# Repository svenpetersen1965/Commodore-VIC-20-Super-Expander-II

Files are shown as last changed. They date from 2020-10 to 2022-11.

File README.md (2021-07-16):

# Commodore-VIC-20-Super-Expander-II
This is a reverse engineered  Commodore Super Expander cartridge which does not have the original ROM pinouts, but fits 27C512 EPROMs. The 8k memory bank and the other configuration can be  selected with jumpers or solder bridges.

This cartridge provides a 3k RAM expansion (required for Super Expander) and up to two EPROMs and is of general use for games and especially the VIC-20 diagnostic software.

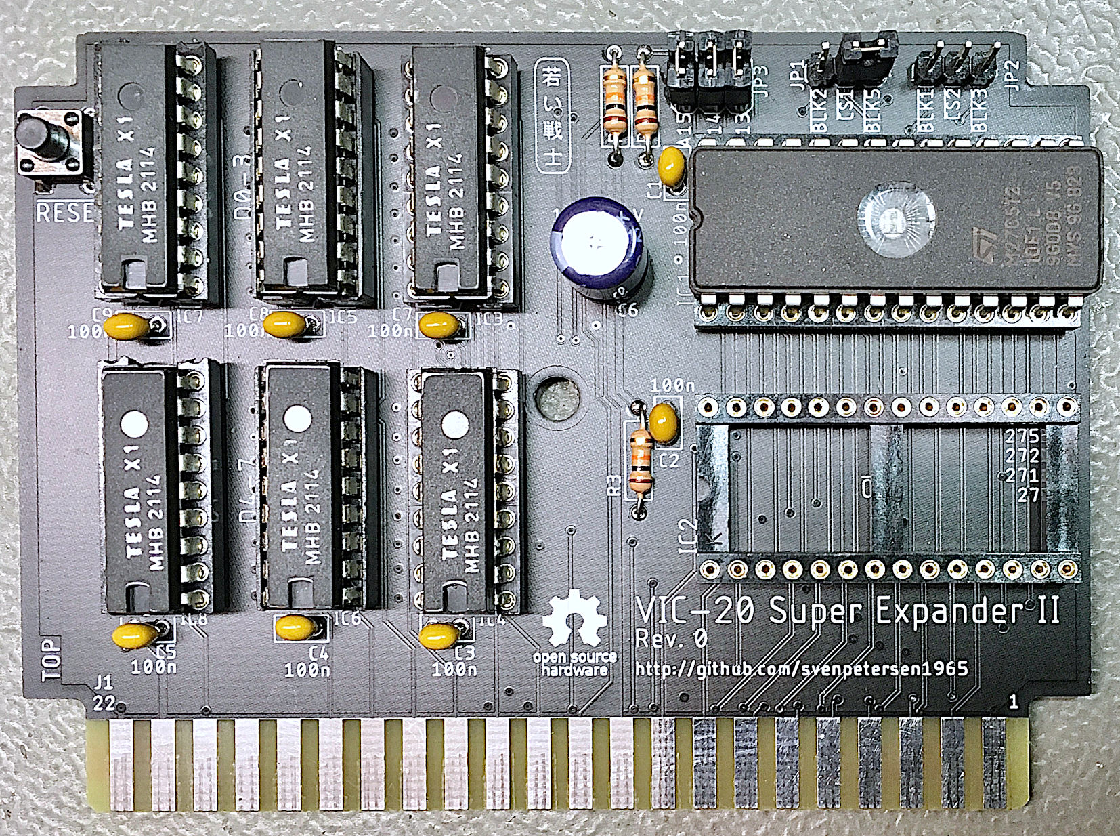
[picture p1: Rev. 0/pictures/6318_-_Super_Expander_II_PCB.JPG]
Super Expander II


Please also check my <a href="http://tech.guitarsite.de/vic-20_super_expanderii.html">website</a>.

BOM value (full): 21.39€ (12.12.2020)

# Rev. 1

Rev. 1 allows to select a software size of 4k and 8k. This allows to combine the super expander software with a cartridge that resides at $B000. This requires a multi cartridge box (like the VC-1020). It is for 100% compatibility to teh original. Also a new logo was introduced.

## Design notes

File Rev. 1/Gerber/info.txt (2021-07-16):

      
       Board: VIC20_SExpII
       Rev.:  1
  
       Files:
       ======
  
       All Gerber files are generated in extended gerber format (RS274X)
       *.TOP        : Film top copper
       *.BOT        :  -"- bottom copper
       *.STC        :  -"- top soldermask 
       *.STS        :  -"- bottom soldermask
       *.PLC        :  -"- silk screen top
       *.DK         : Drills plated Through (Excellon)
       *.NDK        : Drills not plated Through (Excellon)
       *.OUT        : Board outline

       Board Size:
       ===========
       Length     :   102.0 mm
       Width      :   75.0 mm
       Thickness  :   1.6 mm
       Material   :   FR 4
       Copper     :   35 um
       Surface    :   HASL
       
       Remarks:
       ========
       Width >= 8mil
       Distance >= 6mil
       Drill >= 0.35mm

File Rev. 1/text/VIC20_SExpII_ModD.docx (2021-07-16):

Commodore VIC-20: Super Expander II Rev. 1

Module Description

# General Description

The original Commodore VIC-1211A Super Expander is a Basic Extension, which contains high resolution graphics and sound commands and additional 3kB of RAM. It is a pretty versatile cartridge, which allows up to two 2364 ROMs, that can be configured to use either the 8k chip-selects /BLK2, /BLK5, /BLK1or /BLK3. The configuration is done with solder bridges.

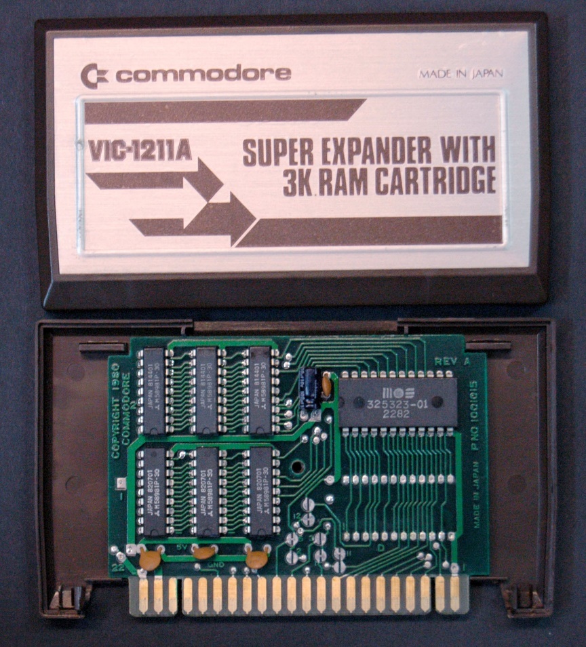
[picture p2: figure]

Figure 1: The Commodore VIC-1211A Super Expander Cartridge

With less RAM (1k) and another software, the same PCB is used as a (Commodore) diagnostic cartridge for the VIC-20.

The disadvantage for own projects is the usage of 2364/2332 ROMs. Thus, the Super Expander II is a version of the original Super Expander cartridge that can fit up to two 27C512 EPROMs. The configuration is done with jumpers, which also work as solder bridges (no pin header required), in case the configuration is not desired to be changed.

Two of the chip-select signals apply to each EPROM. The 8k memory bank can be selected with three jumpers. The selection applies to both EPROMs.

The 2114 4x1k (static) RAMs are the same, like in the original Super Expander. They are still available from some retro computer stores for a comparatively good price and also from AliExpress (search term “upd2114”).

# Configuration

## Chip selects

EPROM | Jumper | Chip Select | VIC-20 Address
IC1 | JP1 | | $4000 - $5FFF
| | | $A000 - $BFFF
IC2 | JP2 | | $2000 - $3FFF
| | | $6000 - $7FFF

Table 1: Configurable Chip Selects

## RAM Address

RAM | Chip Select | VIC-20 Address
IC3 (bit 0-3) IC4 (bit 4-7) | | $0400 - $07FF
IC5 (bit 0-3) IC6 (bit 4-7) | | $0800 - $0BFF
IC7 (bit 0-3) IC8 (bit 4-7) | | $0C00 - $0FFF

Table 2: Mapping of the RAM ICs

## Software Size

The original Super Expander used a 2332 ROM, which had a 2nd, low active chip select input, which disabled the ROM while A12 (connected to this 2nd input) was HIGH. This way, the Super Expander can be combined with cartridges, that use the $B000 - $BFFF address space, like the machine language monitor cartridge. The Super Expander II resembles this behavior by optionally setting the chip enable input of the EPROMs HIGH (with A12). This can be selected with JP4 (for IC1) or JP5 (for IC2) being set to “4k”. Default setting is “8k” (chip enable = LOW).

The address range of the EPROMs (as seen by the CPU) with JP4 ond/or JP5 set to “4k”

EPROM | Jumper | Chip Select | VIC-20 Address
IC1 | JP1 | | $4000 - $4FFF
| | | $A000 - $AFFF
IC2 | JP2 | | $2000 - $2FFF
| | | $6000 - $6FFF

## Memory Bank Select

There are two different types of addresses mentioned in this document:

- VIC-20 Address
- EPROM Offset Address

Both types must not be confused! The EPROM Offset Address is the address of the selected memory bank within (the program buffer of the EPROM). This is, where you load the different binary files to the EPROM buffer. One of those memory banks is selected with the Jumper JP3. This appears in/is mapped to the VIC-20 memory at the address determined by the chip select (see Table 1).

JP3 | | | Address Bits | | | EPROM Address (Offset)
A15 | A14 | A35 | A15 | A14 | A13
SET | SET | SET | L | L | L | 0x0000 – 0x1FFF
SET | SET | OPEN | L | L | H | 0x2000 – 0x3FFF
SET | OPEN | SET | L | H | L | 0x4000 – 0x5FFF
SET | OPEN | OPEN | L | H | H | 0x6000 – 0x7FFF
OPEN | SET | SET | H | L | L | 0x8000 – 0x9FFF
OPEN | SET | OPEN | H | L | H | 0xA000 – 0xBFFF
OPEN | OPEN | SET | H | H | L | 0xC000 – 0xDFFF
OPEN | OPEN | OPEN | H | H | H | 0xE000 – 0xFFFF

Table 3: 8k cartridges memory banks

# EPROMs

Four different types/sizes of EPROMs can be used with the Super Expander II, not all settings make sense with them. Their pin out is shown in Table 4.

The effect of the settings and the recommended configurations are shown in Table 5.

27C64
| 27C128
| | 27C256
| | | 27C512
| | | | SOCKET
Vpp | Vpp | Vpp | A15 | 1 | A15 | VCC | 28 | VCC | VCC | VCC | VCC
A12 | A12 | A12 | A12 | 2 | A12 | A14 | 27 | A14 | A14 | /PGM | /PGM
A7 | A7 | A7 | A7 | 3 | A7 | A13 | 26 | A13 | A13 | A13 | n.c.
A6 | A6 | A6 | A6 | 4 | A6 | A8 | 25 | A8 | A8 | A8 | A8
A5 | A5 | A5 | A5 | 5 | A5 | A9 | 24 | A9 | A9 | A9 | A9
A4 | A4 | A4 | A4 | 6 | A4 | A11 | 23 | A11 | A11 | A11 | A11
A3 | A3 | A3 | A3 | 7 | A3 | /OE | 22 | /G/Vpp | /G | /G | /G
A2 | A2 | A2 | A2 | 8 | A2 | A10 | 21 | A10 | A10 | A10 | A10
A1 | A1 | A1 | A1 | 9 | A1 | GND | 20 | /E | /E | /E | /E
A0 | A0 | A0 | A0 | 10 | A0 | D7 | 19 | D7 | D7 | D7 | D7
D0 | D0 | D0 | D0 | 11 | D0 | D6 | 18 | D6 | D6 | D6 | D6
D1 | D1 | D1 | D1 | 12 | D1 | D5 | 17 | D5 | D5 | D5 | D5
D2 | D2 | D2 | D2 | 13 | D2 | D4 | 16 | D4 | D4 | D4 | D4
GND | GND | GND | GND | 14 | GND | D3 | 15 | D3 | D3 | D3 | D3

Table 4: EPROM pin compatibility

EPROM | Size | A15 | A14 | A13
27C512 | 64kx8 | yes | yes | yes
27C256 | 32kx8 | HIGH | yes | yes
27C128 | 16kx8 | HIGH | HIGH | yes
27C64 | 8kx8 | HIGH | HIGH | HIGH

Table 5: Settings per EPROM type

In case Vpp is located at a dedicated pin (pin 1), A15 has no effect anymore. A HIGH level is recommended (switch is off). The /PGM Pin should be set HIGH. The n.c. (not connected) pin should be HIGH (with pull-up resistor) or open.

# Using parallel EEPROMs

There are parallel EPROMs, which fit into the EPROM sockets. They do not require erasing with a UV eraser, like EPROMs, but the price is higher.

Since they can be written, which is controlled by the signal, but the Super Expander II cartridge is lacking of this functionality, this signal has to be HIGH (inactive). The 28C256 has the A14 signal connected to Pin 1, which is A15 of the EEPROM socket. This is no problem, but it has to be kept in mind, that the jumper for A15 has effect on the bank select A14 of the EPROM.

28C64
| 28C256
| | SOCKET
n.c. | A14 | 1 | A15 | VCC | 28 | VCC | VCC
A12 | A12 | 2 | A12 | A14 | 27 | /WE | /WE
A7 | A7 | 3 | A7 | A13 | 26 | A13 | n.c
A6 | A6 | 4 | A6 | A8 | 25 | A8 | A8
A5 | A5 | 5 | A5 | A9 | 24 | A9 | A9
A4 | A4 | 6 | A4 | A11 | 23 | A11 | A11
A3 | A3 | 7 | A3 | /OE | 22 | /G/Vpp | /OE
A2 | A2 | 8 | A2 | A10 | 21 | A10 | A10
A1 | A1 | 9 | A1 | GND | 20 | /E | /CE
A0 | A0 | 10 | A0 | D7 | 19 | D7 | D7
D0 | D0 | 11 | D0 | D6 | 18 | D6 | D6
D1 | D1 | 12 | D1 | D5 | 17 | D5 | D5
D2 | D2 | 13 | D2 | D4 | 16 | D4 | D4
GND | GND | 14 | GND | D3 | 15 | D3 | D3

Table 6: EEPROM pin compatibility

EEPROM | Size | A15 | A14 | A13
28C256 | 32kx8 | =A14 | OPEN | yes
28C64 | 8kx8 | OPEN | OPEN | OPEN

Table 7: Settings per EEPROM type

# Dimensions

The dimensions of the Super Expander II are identical to those of the original super Expander PCB.

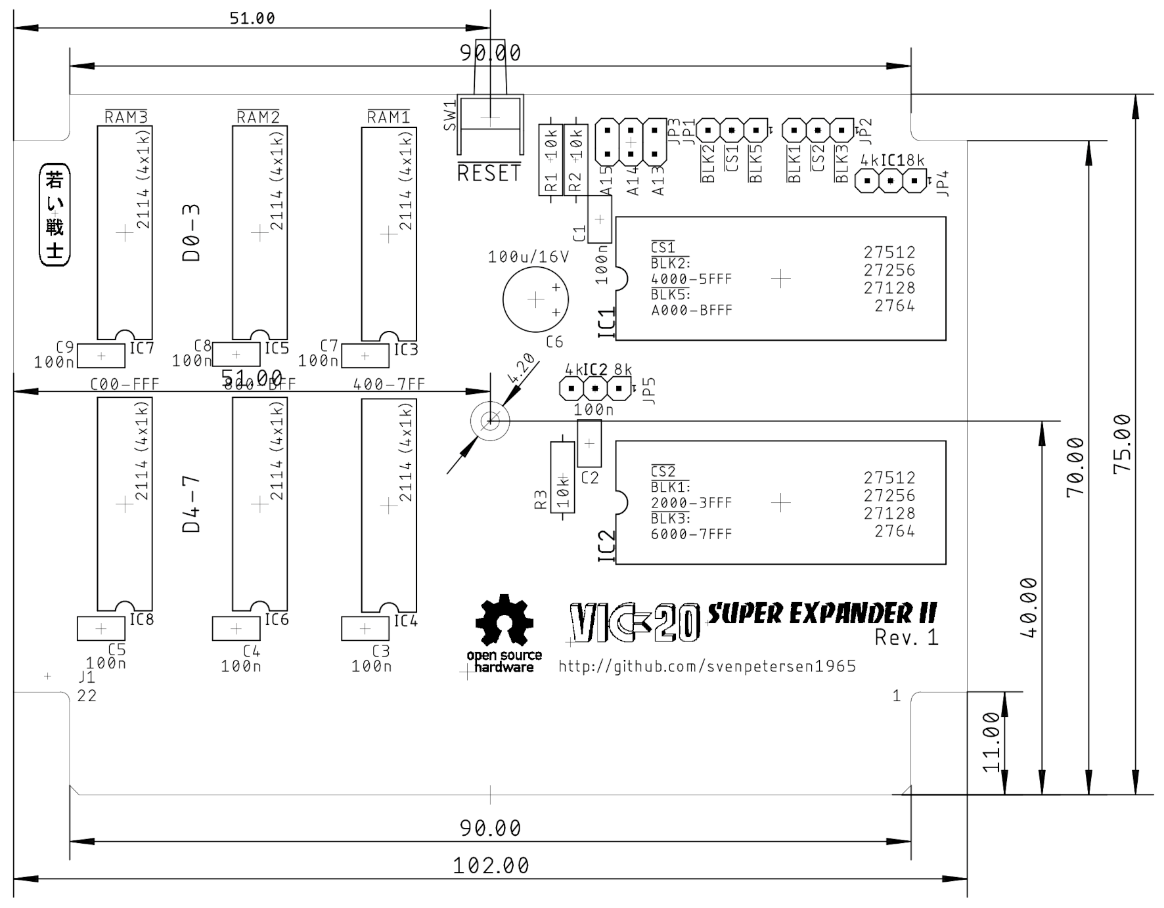
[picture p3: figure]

Figure 2: Dimensions of the Super Expander II

The PCB fits the original super Expander cartridge case, another VIC-20 cartridge case from Commodore or the tfw8bit.com cartridge case.

The VIC-20 cartridge cases are high enough to fits the Super Expander II PCB even with the ICs on sockets and vertical jumpers. This has been verified for the Super Expander case and the tfw8bit case. The tfw8bit case and the “other Commodore VIC-20” cases require two T-shaped board supports in the middle of the lower shell to be removed.

# Revision History

## Rev. 0

- Prototype: Fully functional.

## Rev. 1

- 4k address decoding (lower 4k) enabled
- Type and location of reset switch changed
- Cool new logo

VIC20_SExpII_ModD.docx 16.07.2021 15:38 Drafted by Sven Petersen Page 2 of 2 Doc.-No.: 157-6-01-01

VIC20_SExpII_ModD.docx 16.07.2021 15:38 Drafted by Sven Petersen Page 1 of 1 Doc.-No.: 1-6-00-00

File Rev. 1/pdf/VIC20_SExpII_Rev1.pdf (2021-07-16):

# Project Documentation

## Commodore VIC-20: Super Expander II

## Project number: 157

## Revision: 1

## Date: 16.07.2021

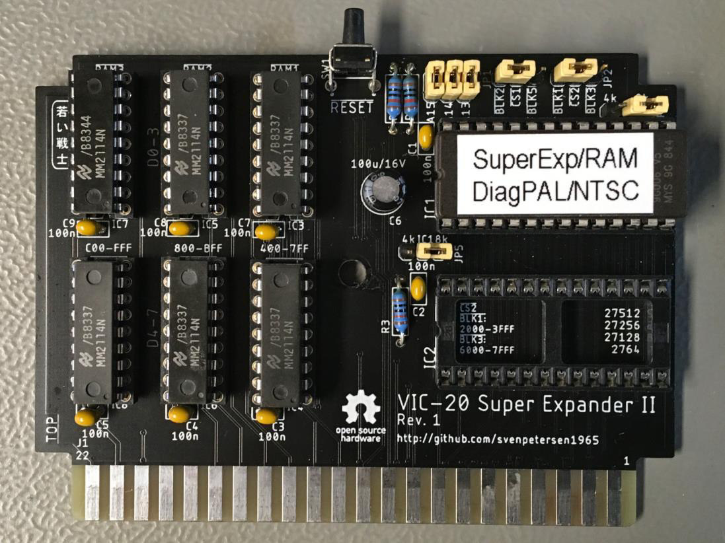
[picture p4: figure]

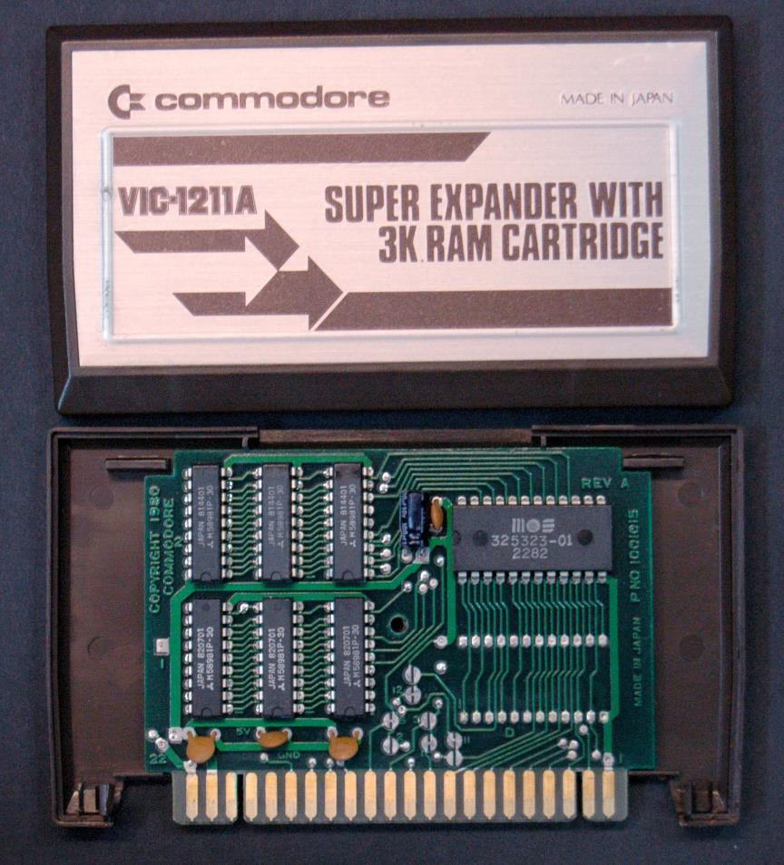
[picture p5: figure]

VIC20_SExpII_ModD.docx | | 16.07.2021 15:38
Drafted by Sven Petersen | Page 1 of 6 | Doc.-No.: 157-6-01-01

### Commodore VIC-20: Super Expander II Rev. 1

### Module Description

## General Description

The original Commodore VIC-1211A Super Expander is a Basic Extension, which contains high resolution graphics and sound commands and additional 3kB of RAM. It is a pretty versatile cartridge, which allows up to two 2364 ROMs, that can be configured to use either the 8k chip-selects /BLK2, /BLK5, /BLK1or /BLK3. The configuration is done with solder bridges.

Figure 1: The Commodore VIC-1211A Super Expander Cartridge

With less RAM (1k) and another software, the same PCB is used as a (Commodore) diagnostic cartridge for the VIC-20.

The disadvantage for own projects is the usage of 2364/2332 ROMs. Thus, the Super Expander II is a version of the original Super Expander cartridge that can fit up to two
27C512 EPROMs. The configuration is done with jumpers, which also work as solder bridges (no pin header required), in case the configuration is not desired to be changed.

Two of the chip-select signals apply to each EPROM. The 8k memory bank can be selected with three jumpers. The selection applies to both EPROMs.

The 2114 4x1k (static) RAMs are the same, like in the original Super Expander. They are still available from some retro computer stores for a comparatively good price and also from
AliExpress (search term “upd2114”).

VIC20_SExpII_ModD.docx | | 16.07.2021 15:38
Drafted by Sven Petersen | Page 2 of 6 | Doc.-No.: 157-6-01-01

## Configuration

### Chip selects

EPROM | Jumper | Chip Select | VIC-20 Address
IC1 | JP1 | BLK2 | $4000 - $5FFF
| | BLK5 | $A000 - $BFFF
IC2 | JP2 | BLK1 | $2000 - $3FFF
| | BLK3 | $6000 - $7FFF

Table 1: Configurable Chip Selects

### RAM Address

RAM | Chip Select | VIC-20 Address
IC3 (bit 0-3) IC4 (bit 4-7) | RAM1 | $0400 - $07FF
IC5 (bit 0-3) IC6 (bit 4-7) | RAM2 | $0800 - $0BFF
IC7 (bit 0-3) IC8 (bit 4-7) | RAM3 | $0C00 - $0FFF

Table 2: Mapping of the RAM ICs

### Software Size

The original Super Expander used a 2332 ROM, which had a 2nd, low active chip select input, which disabled the ROM while A12 (connected to this 2nd input) was HIGH. This way, the Super Expander can be combined with cartridges, that use the $B000 - $BFFF address space, like the machine language monitor cartridge. The Super Expander II resembles this behavior by optionally setting the chip enable input of the EPROMs HIGH (with A12). This can be selected with JP4 (for
IC1) or JP5 (for IC2) being set to “4k”. Default setting is “8k” (chip enable = LOW).

### The address range of the EPROMs (as seen by the CPU) with JP4 ond/or JP5 set to “4k”

EPROM | Jumper | Chip Select | VIC-20 Address
IC1 | JP1 | BLK2 | $4000 - $4FFF
| | BLK5 | $A000 - $AFFF
IC2 | JP2 | BLK1 | $2000 - $2FFF
| | BLK3 | $6000 - $6FFF

VIC20_SExpII_ModD.docx | | 16.07.2021 15:38
Drafted by Sven Petersen | Page 3 of 6 | Doc.-No.: 157-6-01-01

### Memory Bank Select

There are two different types of addresses mentioned in this document:

- VIC-20 Address
- EPROM Offset Address

Both types must not be confused! The EPROM Offset Address is the address of the selected memory bank within (the program buffer of the EPROM). This is, where you load the different binary files to the EPROM buffer. One of those memory banks is selected with the Jumper JP3. This appears in/is mapped to the VIC-20 memory at the address determined by the chip select BLK1/2/3/5 (see Table 1).

JP3 | Address Bits | EPROM Address
A15 | A14 | A35 | A15 | A14 | A13 | (Offset)
SET | SET | SET | L | L | L | 0x0000 – 0x1FFF
SET | SET | OPEN | L | L | H | 0x2000 – 0x3FFF
SET | OPEN | SET | L | H | L | 0x4000 – 0x5FFF
SET | OPEN | OPEN | L | H | H | 0x6000 – 0x7FFF
OPEN | SET | SET | H | L | L | 0x8000 – 0x9FFF
OPEN | SET | OPEN | H | L | H | 0xA000 – 0xBFFF
OPEN | OPEN | SET | H | H | L | 0xC000 – 0xDFFF
OPEN | OPEN | OPEN | H | H | H | 0xE000 – 0xFFFF
Table 3: 8k cartridges memory banks

VIC20_SExpII_ModD.docx | | 16.07.2021 15:38
Drafted by Sven Petersen | Page 4 of 6 | Doc.-No.: 157-6-01-01

## EPROMs

Four different types/sizes of EPROMs can be used with the Super Expander II, not all settings make sense with them. Their pin out is shown in Table 4.

The effect of the settings and the recommended configurations are shown in Table 5.

27C64
| 27C128
| 27C256
| 27C512
| SOCKET
Vpp | Vpp | Vpp | A15 | 1 | A15 | VCC | 28 | VCC | VCC | VCC | VCC
A12 | A12 | A12 | A12 | 2 | A12 | A14 | 27 | A14 | A14 | /PGM | /PGM
A7 | A7 | A7 | A7 | 3 | A7 | A13 | 26 | A13 | A13 | A13 | n.c.
A6 | A6 | A6 | A6 | 4 | A6 | A8 | 25 | A8 | A8 | A8 | A8
A5 | A5 | A5 | A5 | 5 | A5 | A9 | 24 | A9 | A9 | A9 | A9
A4 | A4 | A4 | A4 | 6 | A4 | A11 | 23 | A11 | A11 | A11 | A11
A3 | A3 | A3 | A3 | 7 | A3 | /OE | 22 | /G/Vpp | /G | /G | /G
A2 | A2 | A2 | A2 | 8 | A2 | A10 | 21 | A10 | A10 | A10 | A10
A1 | A1 | A1 | A1 | 9 | A1 | GND | 20 | /E | /E | /E | /E
A0 | A0 | A0 | A0 | 10 | A0 | D7 | 19 | D7 | D7 | D7 | D7
D0 | D0 | D0 | D0 | 11 | D0 | D6 | 18 | D6 | D6 | D6 | D6
D1 | D1 | D1 | D1 | 12 | D1 | D5 | 17 | D5 | D5 | D5 | D5
D2 | D2 | D2 | D2 | 13 | D2 | D4 | 16 | D4 | D4 | D4 | D4
GND | GND | GND | GND | 14 | GND | D3 | 15 | D3 | D3 | D3 | D3
Table 4: EPROM pin compatibility
EPROM | Size | A15 | A14 | A13
27C512 | 64kx8 | yes | yes | yes
27C256 | 32kx8 | HIGH | yes | yes
27C128 | 16kx8 | HIGH | HIGH | yes
27C64 | 8kx8 | HIGH | HIGH | HIGH
Table 5: Settings per EPROM type

In case Vpp is located at a dedicated pin (pin 1), A15 has no effect anymore. A HIGH level is recommended (switch is off). The /PGM Pin should be set HIGH. The n.c. (not connected) pin should be HIGH (with pull-up resistor) or open.

VIC20_SExpII_ModD.docx | | 16.07.2021 15:38
Drafted by Sven Petersen | Page 5 of 6 | Doc.-No.: 157-6-01-01

## Using parallel EEPROMs

There are parallel EPROMs, which fit into the EPROM sockets. They do not require erasing with a UV eraser, like EPROMs, but the price is higher.

Since they can be written, which is controlled by the WE signal, but the Super Expander II cartridge is lacking of this functionality, this signal has to be HIGH (inactive). The 28C256 has the A14 signal connected to Pin 1, which is A15 of the EEPROM socket. This is no problem, but it has to be kept in mind, that the jumper for A15 has effect on the bank select A14 of the EPROM.

28C64
| 28C256
| SOCKET
n.c. | A14 | 1 | A15 | VCC | 28 | VCC | VCC
A12 | A12 | 2 | A12 | A14 | 27 | /WE | /WE
A7 | A7 | 3 | A7 | A13 | 26 | A13 | n.c
A6 | A6 | 4 | A6 | A8 | 25 | A8 | A8
A5 | A5 | 5 | A5 | A9 | 24 | A9 | A9
A4 | A4 | 6 | A4 | A11 | 23 | A11 | A11
A3 | A3 | 7 | A3 | /OE | 22 | /G/Vpp | /OE
A2 | A2 | 8 | A2 | A10 | 21 | A10 | A10
A1 | A1 | 9 | A1 | GND | 20 | /E | /CE
A0 | A0 | 10 | A0 | D7 | 19 | D7 | D7
D0 | D0 | 11 | D0 | D6 | 18 | D6 | D6
D1 | D1 | 12 | D1 | D5 | 17 | D5 | D5
D2 | D2 | 13 | D2 | D4 | 16 | D4 | D4
GND | GND | 14 | GND | D3 | 15 | D3 | D3
Table 6: EEPROM pin compatibility
EEPROM | Size | A15 | A14 | A13
28C256 | 32kx8 | =A14 | OPEN | yes
28C64 | 8kx8 | OPEN | OPEN | OPEN
Table 7: Settings per EEPROM type

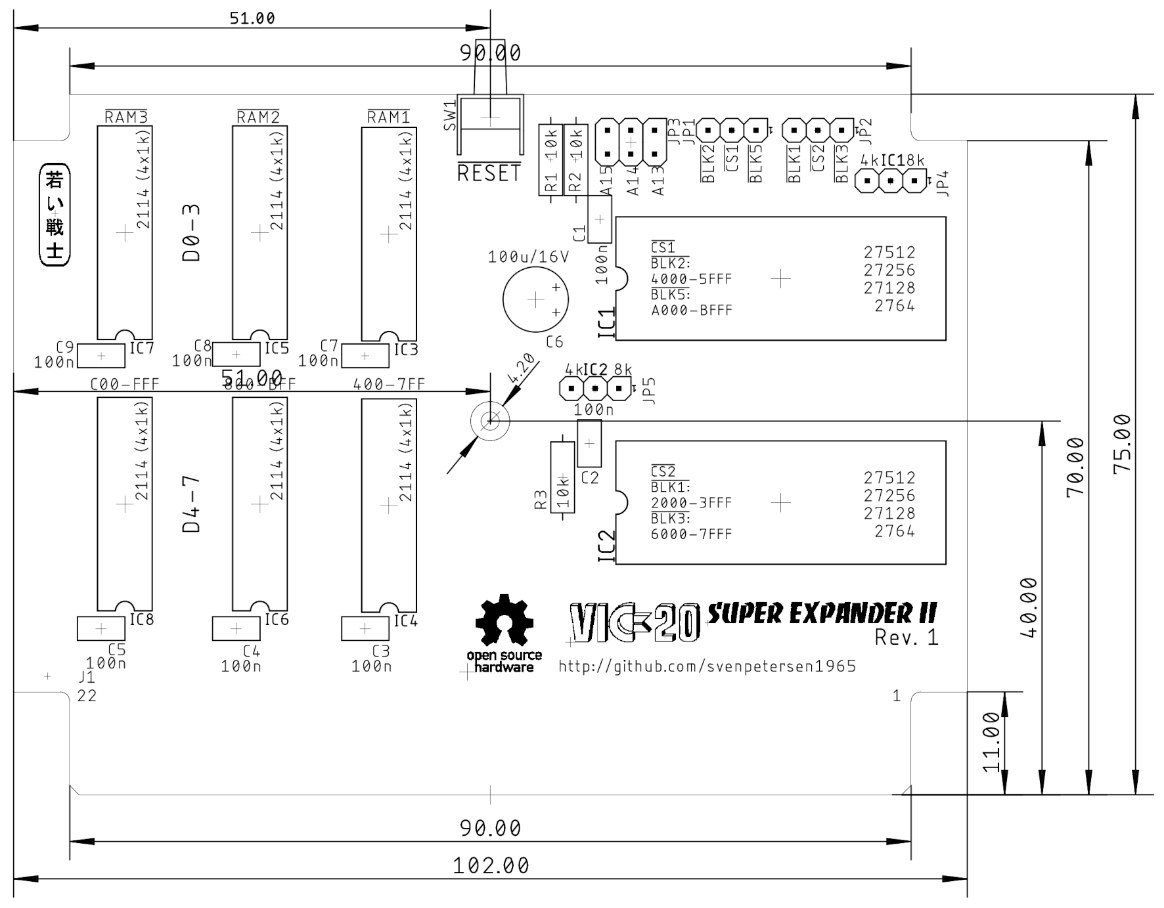
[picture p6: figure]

VIC20_SExpII_ModD.docx | | 16.07.2021 15:38
Drafted by Sven Petersen | Page 6 of 6 | Doc.-No.: 157-6-01-01

## Dimensions

The dimensions of the Super Expander II are identical to those of the original super Expander PCB.

Figure 2: Dimensions of the Super Expander II

The PCB fits the original super Expander cartridge case, another VIC-20 cartridge case from Commodore or the tfw8bit.com cartridge case.

The VIC-20 cartridge cases are high enough to fits the Super Expander II PCB even with the ICs on sockets and vertical jumpers. This has been verified for the Super Expander case and the tfw8bit

### case. The tfw8bit case and the “other Commodore VIC-20” cases require two T-shaped board

supports in the middle of the lower shell to be removed.

## Revision History

### Rev. 0

- Prototype: Fully functional.

### Rev. 1

- 4k address decoding (lower 4k) enabled
- Type and location of reset switch changed
- Cool new logo

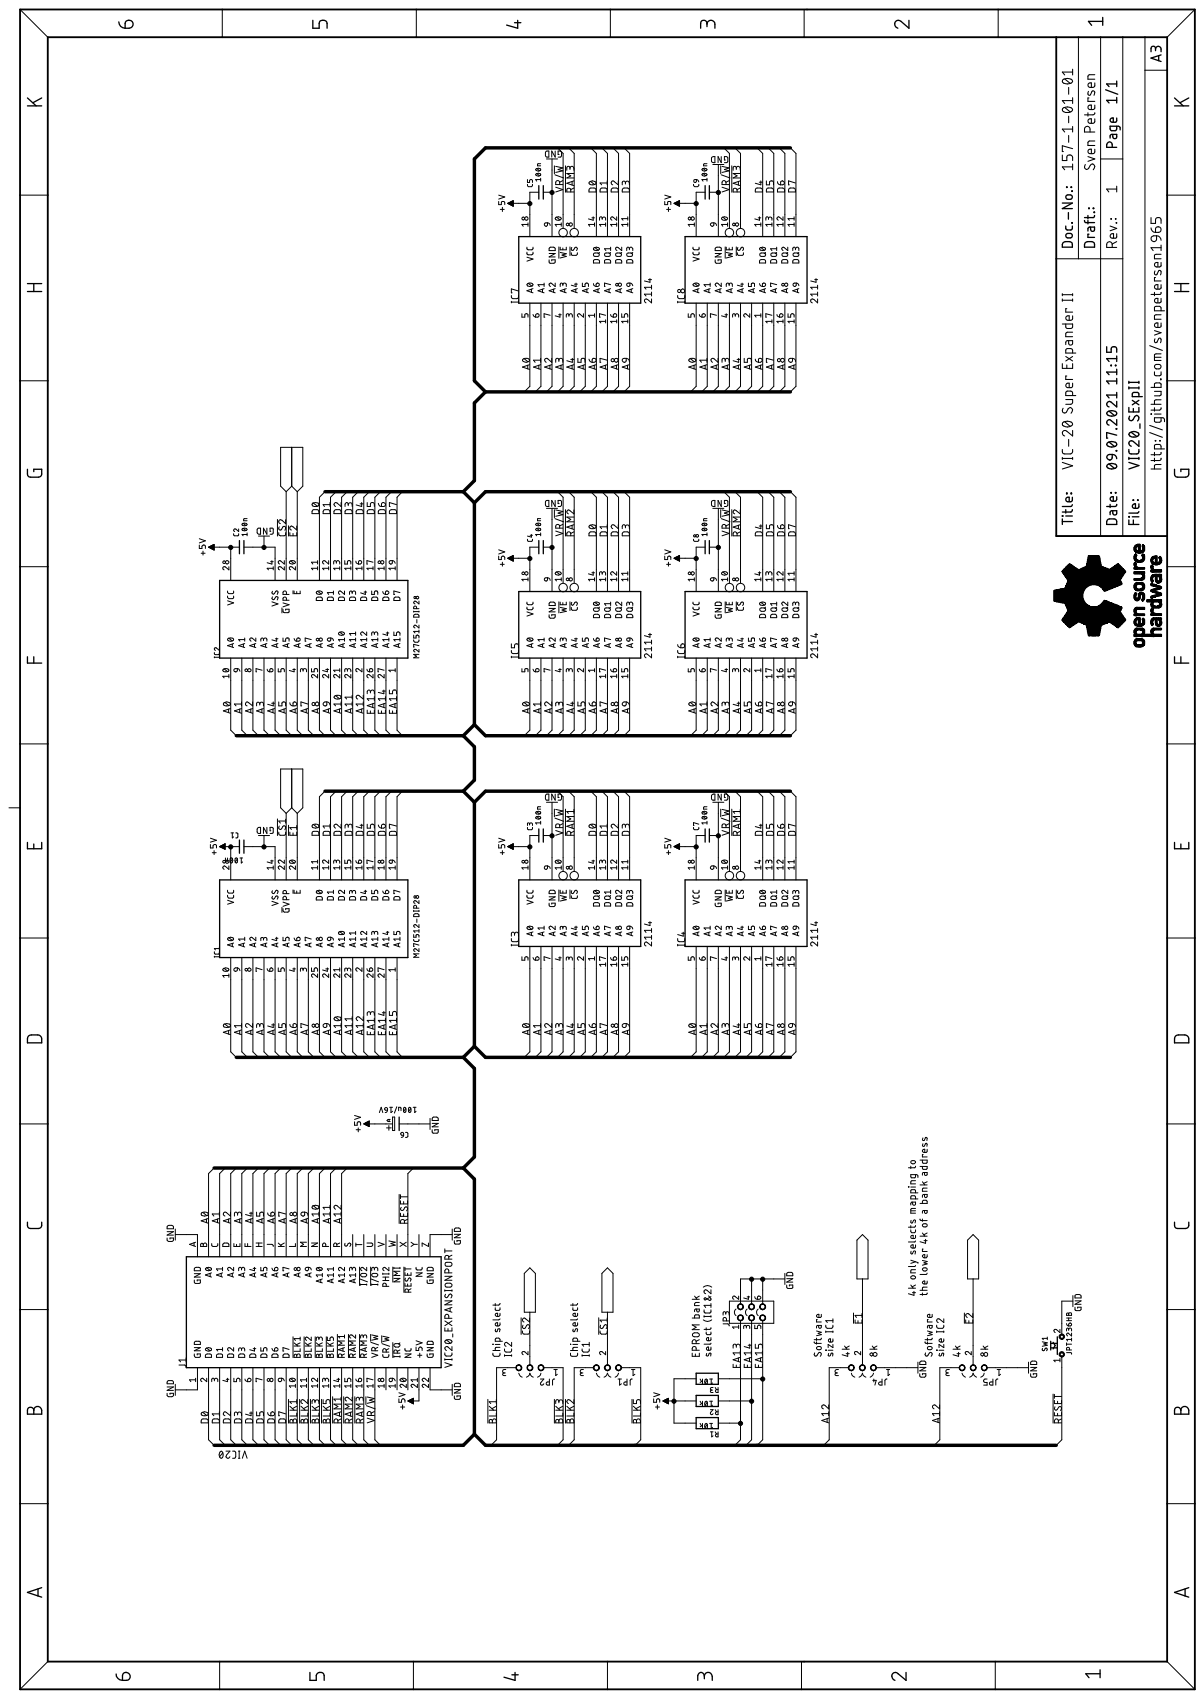
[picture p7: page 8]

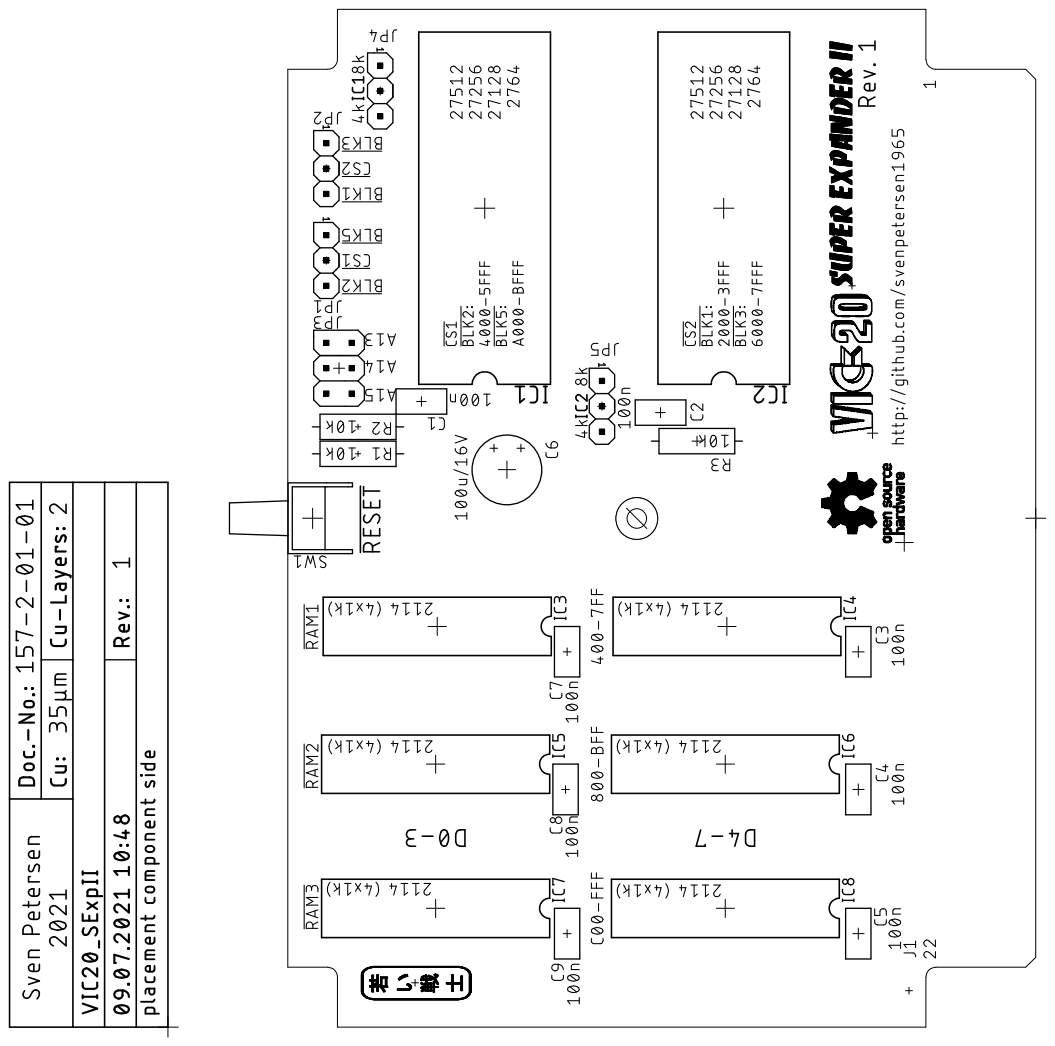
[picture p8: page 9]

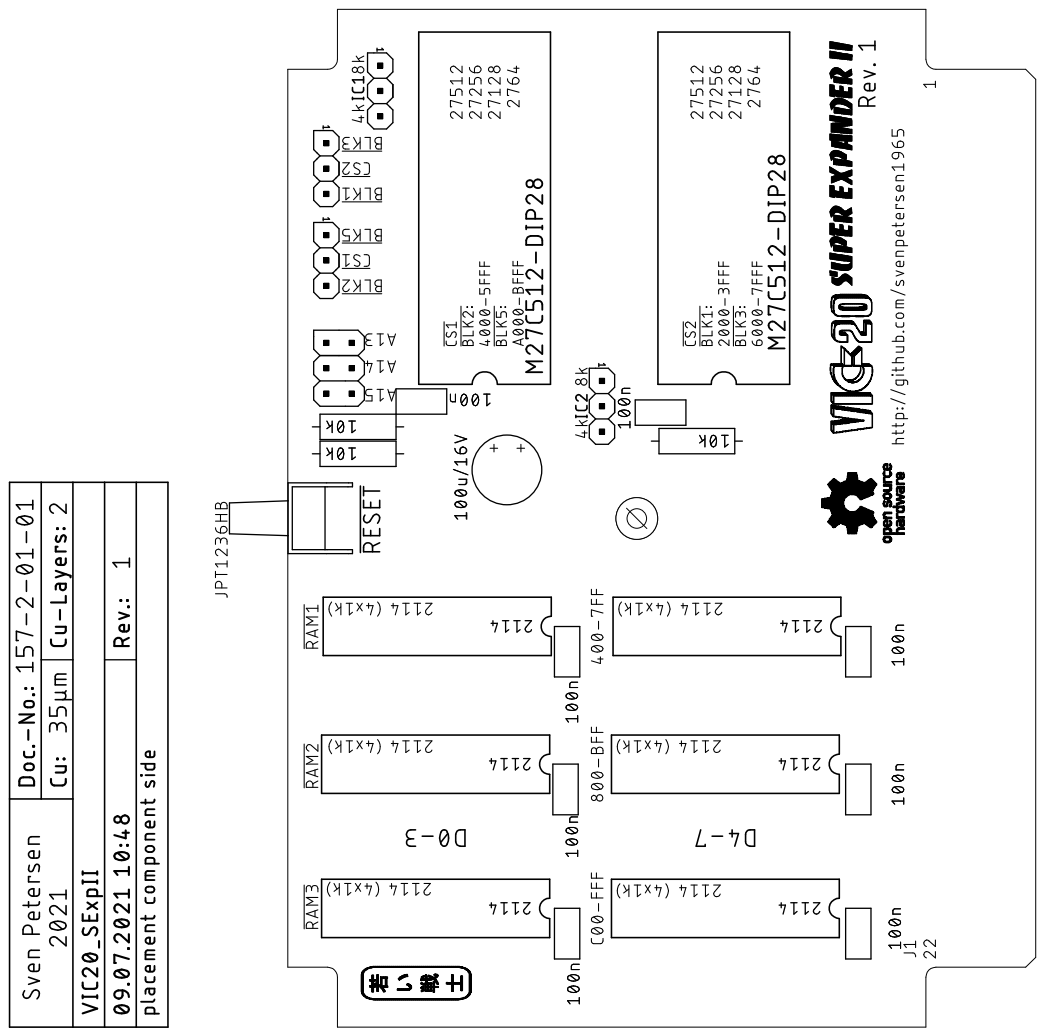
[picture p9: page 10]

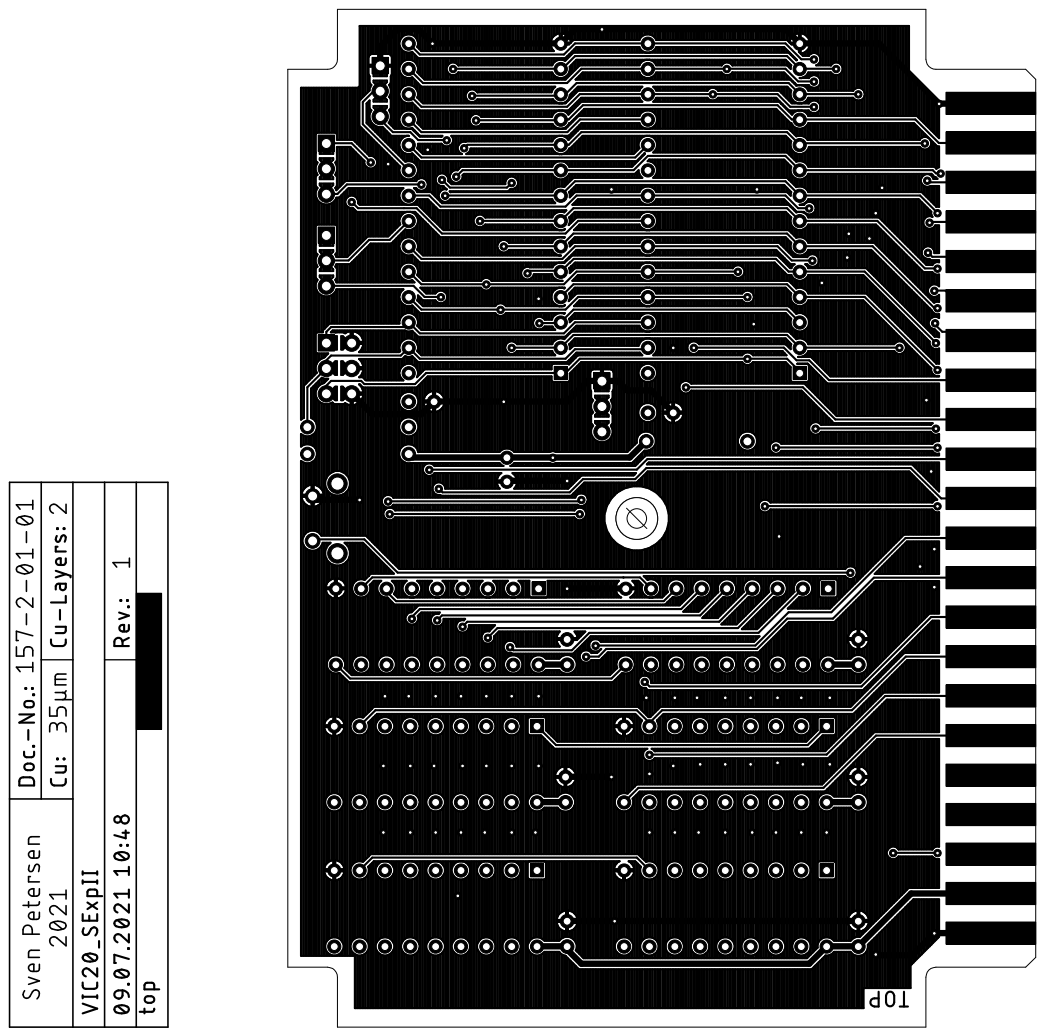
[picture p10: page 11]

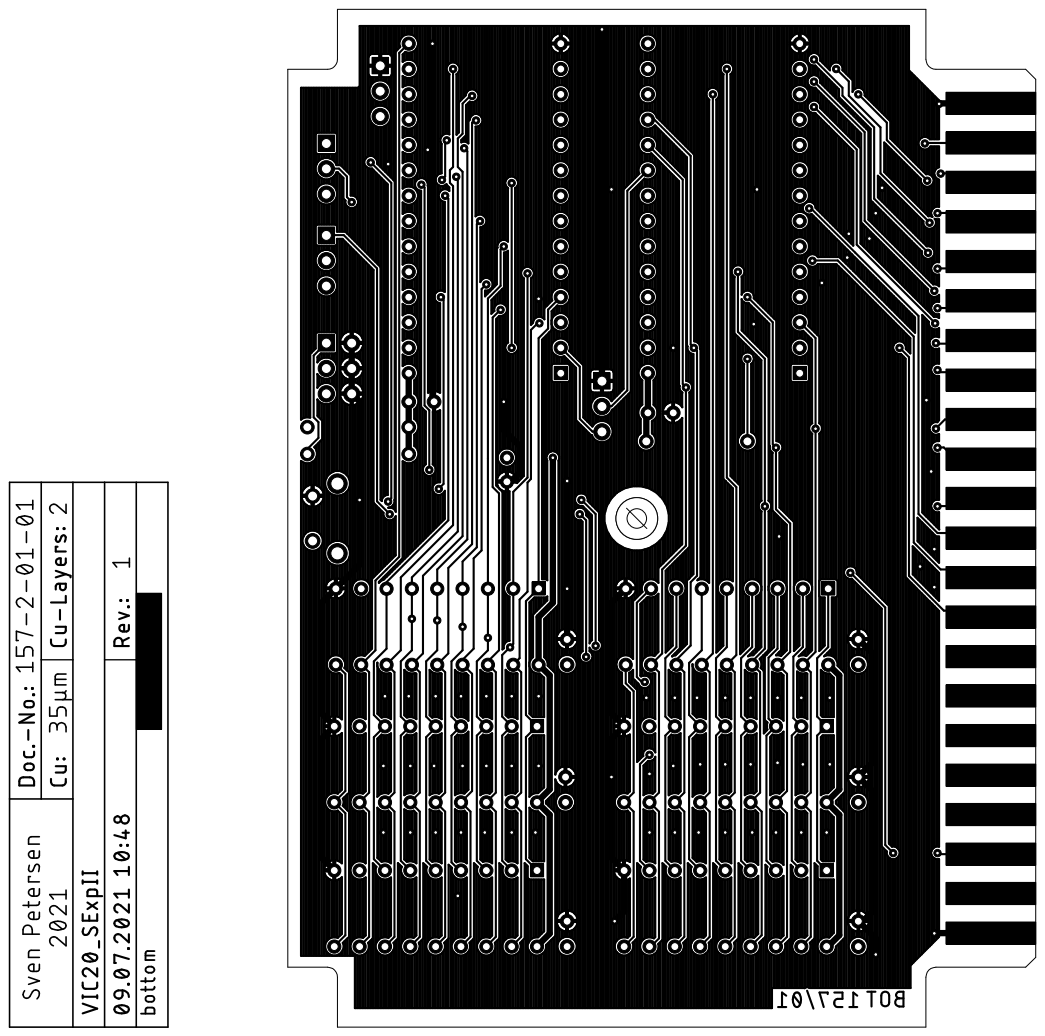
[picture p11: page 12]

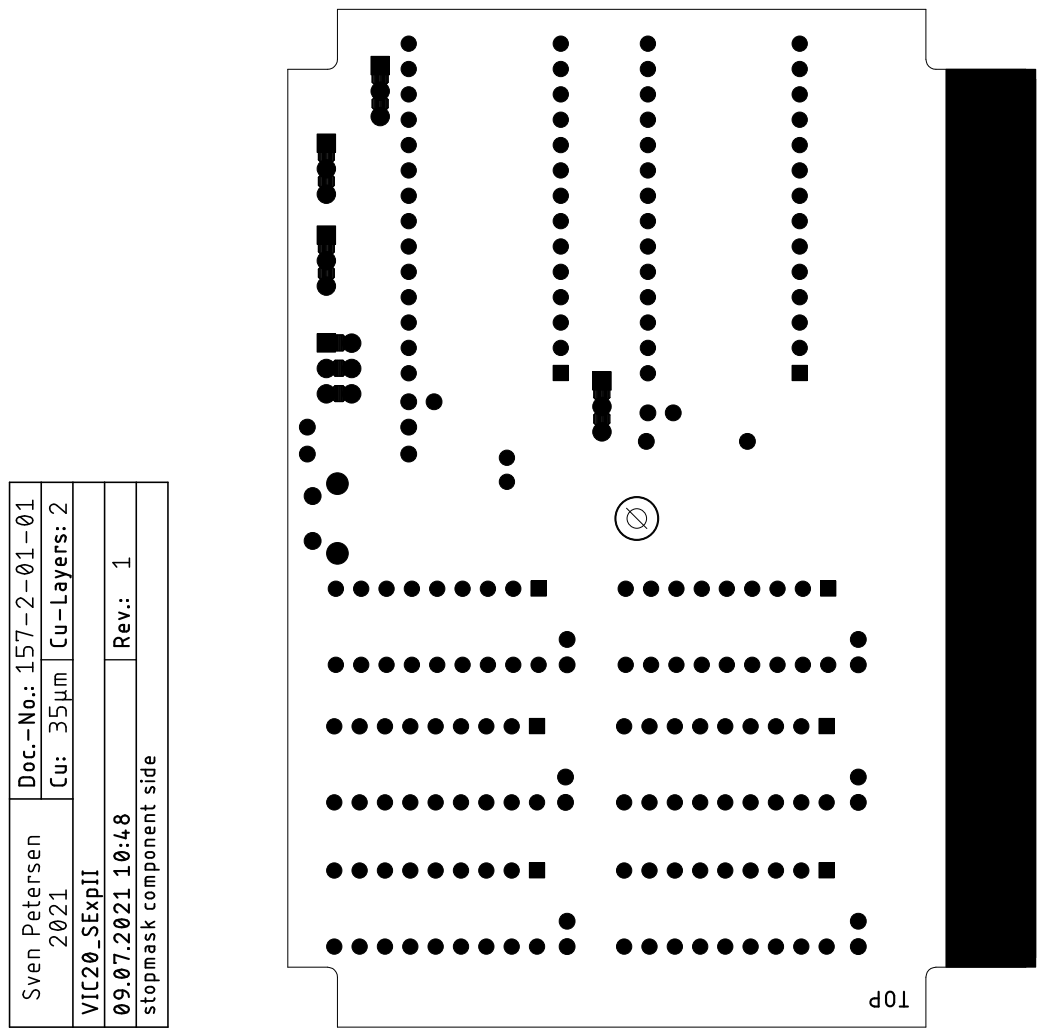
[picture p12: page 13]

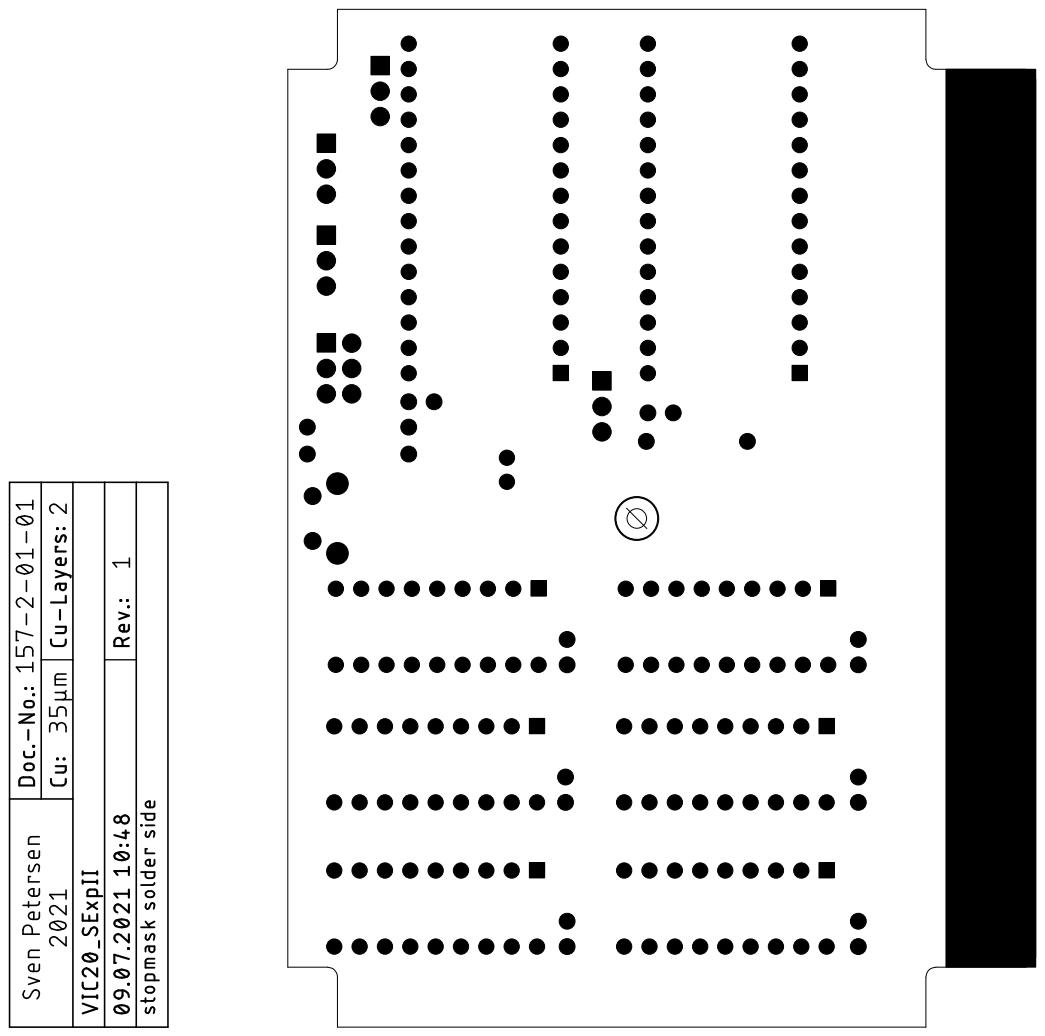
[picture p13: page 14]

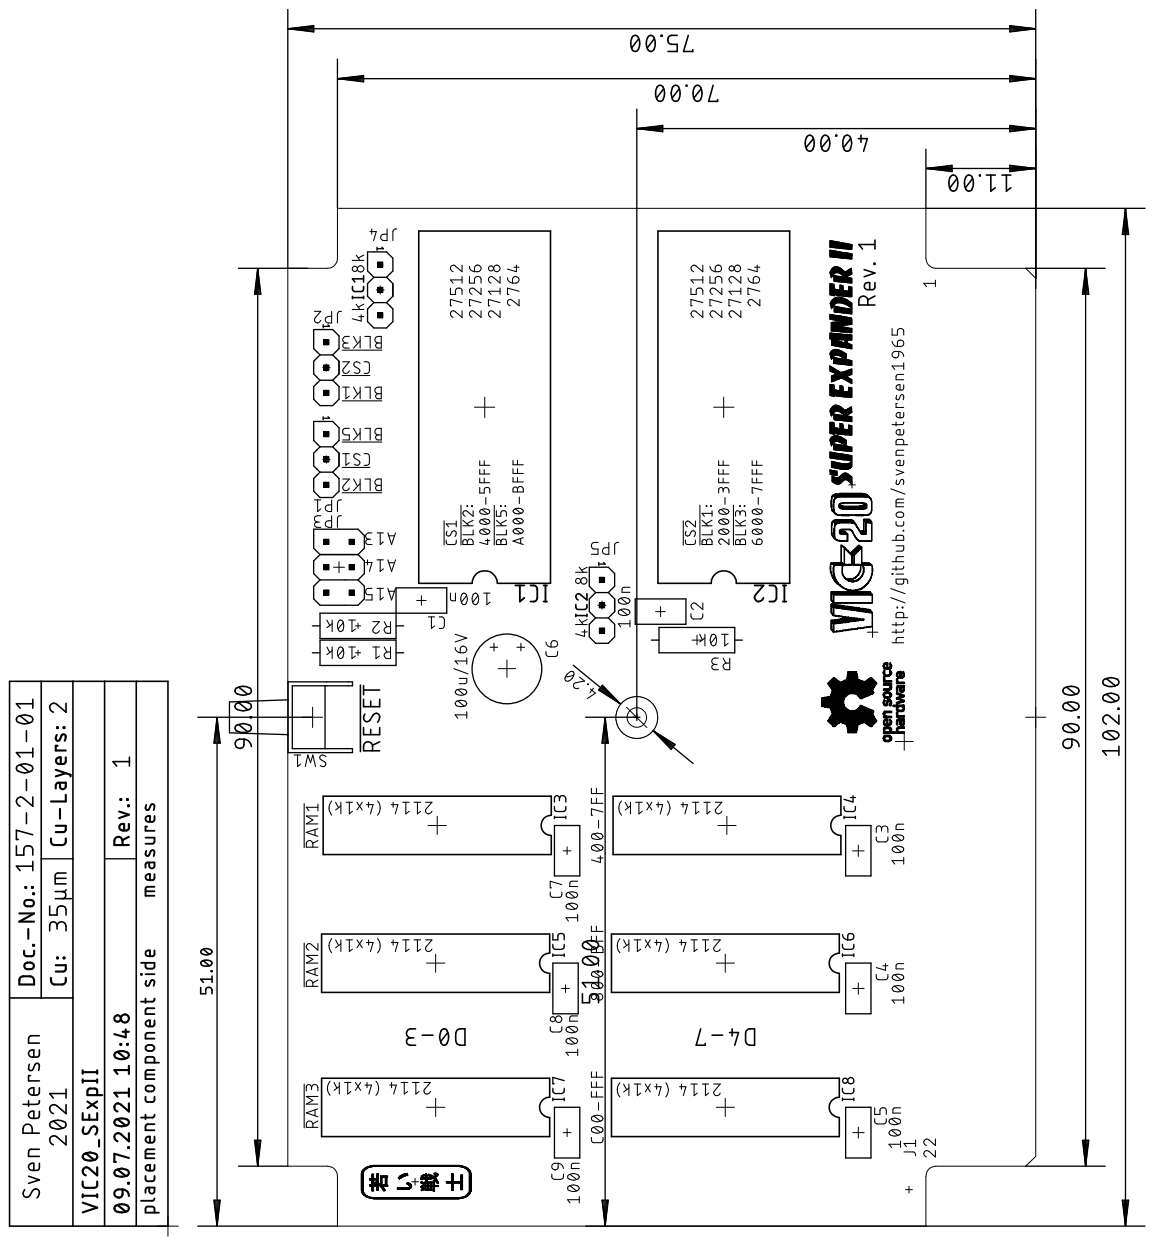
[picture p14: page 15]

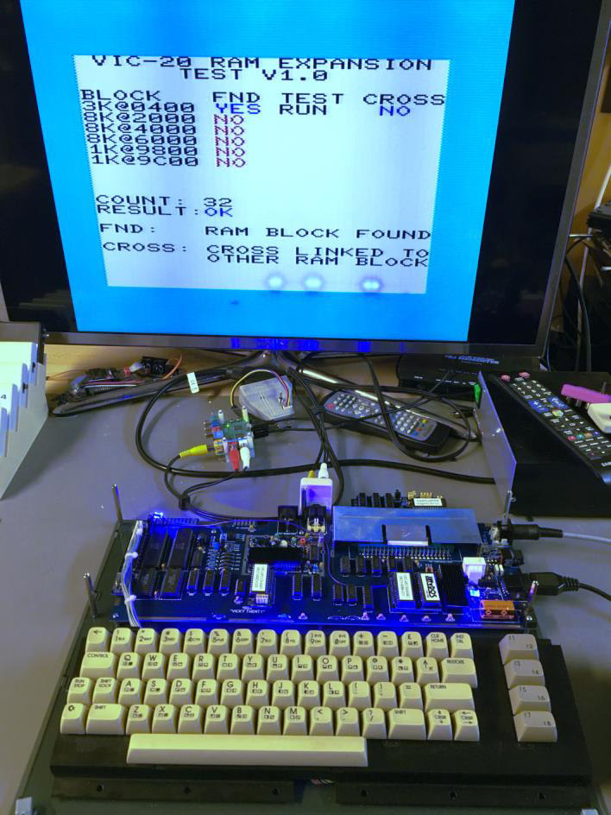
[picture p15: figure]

VIC20_SExpII_Test.docx | | 16.07.2021 16:09
Drafted by Sven Petersen | Page 1 of 4 | Doc.-No.: 157-6-02-01

### Commodore VIC-20: Super Expander II Rev. 1

### Testing

## Test Setup

The tests were conducted with a VickyTwenty (Reproduction of ASSY 250403 Rev. D) and a Super Expander II cartridge (Rev. 1) with 3k of RAM (6 pcs of National Semiconductor MM2114N) and up to two (ST) 27C512 EPROMs (120ns).

Figure 1: Test Setup

## Test Execution

### Super Expander Software

First, the original Super Expander Software from zimmers.net and the Commodore VICMON for $B000 were programed to an EPROM. These two programs fit into one 8k memory bank, since the Super Expander software is a 4k software. The EPROM was inserted the in IC1 socket and CS1 (JP1) was set to BLK5 ($A000-$BFFF). The software size of 8k (for IC1) was set on JP4.

The cartridge was inserted into the VickyTwenty and the computer was switched on. It booted normally and 6519 Bytes Free were reported. The Super Expander requires bytes in RAM, so this is correct.

The function keys produce some of the additional Super Expander instructions. A short program, which is using those instructions, was executed successfully.

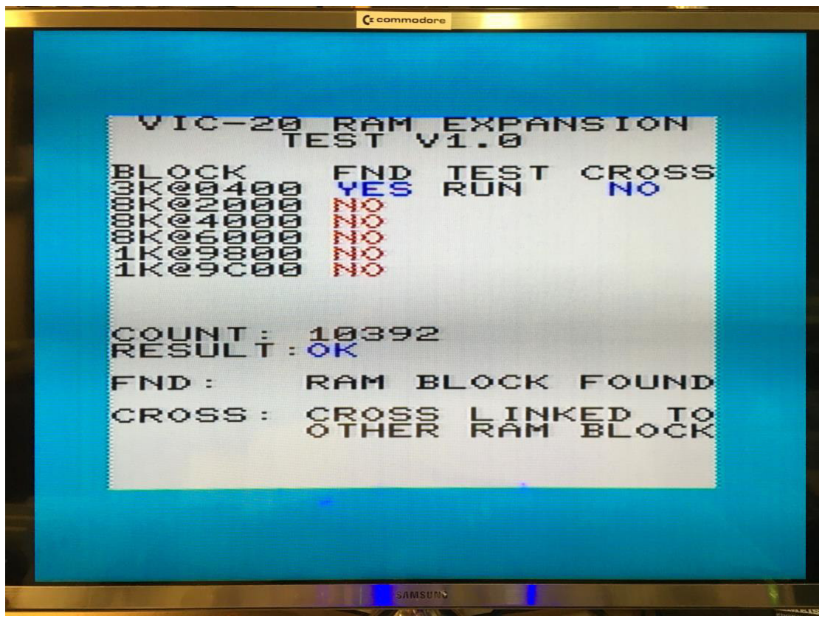
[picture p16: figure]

VIC20_SExpII_Test.docx | | 16.07.2021 16:09
Drafted by Sven Petersen | Page 2 of 4 | Doc.-No.: 157-6-02-01

✓ Function of RAM and EPROM IC1 with BLK5 and the Super Expander Software verified.

SYS11*4096 (which is $B000) started the VICMON.

✓ Additional test.

The software size was configured to 4k (JP4). So, the VICMON was not visible anymore. The VIC-20 booted properly.

SYS11*4096 resulted in a software crash, which shows that the software size selection is working.

✓ Software size selection (4k/8k) for IC1 is working properly.

### RESET Button

The RESET button (SW1) was pressed. The VIC-20 rebooted properly.

✓ RESET button verified

### RAM Expansion Test software

The jumpers on JP3 were set to the 2nd 8k (A15..13: set/set/open), JP1 remained at BLK5 . The software was executed properly. The 3k RAM expansion was found. Over 10,000 test cycles were carried out properly.

✓ The bank selection on JP3 (001) works properly
✓ RAM works properly

Figure 2: 3k RAM Expansion Test

VIC20_SExpII_Test.docx | | 16.07.2021 16:09
Drafted by Sven Petersen | Page 3 of 4 | Doc.-No.: 157-6-02-01

### VIC-20 Diagnostic Software

The software (PAL) also origins from zimmers.net. It was programmed into the 2nd 8k of the said EPROM, a different version of this software (NTSC) was programmed to the 3rd 8k.

The jumpers on JP3 were set to the 3rd 8k (A15..13: set/open/set), JP1 remained at BLK5 .

The diagnostics software started and executed properly (together with the VIC-20 diagnostics harness). For the 2nd version of the diagnostic software, JP3 was set to the 3rd 8k bank (A15..13: set/open/open). This software executed properly, too.

✓ Bank select (000, 001, 010, 011) on JP3 verified

### Game Cartridge Donkey Kong

This game is a 16k game and requires both EPROMs.
The software for $A000 was programmed in a fresh EPROM, which was inserted into IC1. JP1 remained at BLK5 . The other part of the software, which is located at $2000 was programmed

into another fresh EPROM, which was then inserted into the IC2 socket. JP2 was set to BLK1 . All jumpers on JP3 were set.

The software started properly and the game could be played.

✓ EPROM IC2 with BLK1 verified

### Game Cartridge AE

The software origins from zimmers.net. It consisted of two images, one for $A000 and one for $6000. The images were programmed into two EPROMs, the $A000 software was inserted into IC1, the $6000 software into IC2. Jumper JP1 was set to BLK5 , JP2 to BLK3 . The software started properly and the game could be played. The software size (JP4 and JP5) was set to 8k.

✓ EPROM IC2 with BLK3 verified

### VIC-MON (for $4000)

The source of this software is once again zimmers.net. It was programmed into the 5th 8k memory bank (@ buffer address $8000) of an EPROM. The EPROM was inserted into IC1 and JP1 was set to BLK2 .

SYS4x4096 started the software properly.

✓ Bank select (100) on JP3 and BLK2 (JP1) verified

### Installation in cartridge cases

The fully assembled Super Expander II PCB (all ICs on sockets and all vertical jumpers) was installed in the original Commodore Super Expander cartridge case- This could be accomplished without a problem.

The original Commodore Game cartridge case required removing some support structures for small PCBs, after that, it also fit.

The tfw8bit.com VIC-20 cartridge case fits after removing the support structures for the short PCBs.

✓ Dimensions verified

VIC20_SExpII_Test.docx | | 16.07.2021 16:09
Drafted by Sven Petersen | Page 4 of 4 | Doc.-No.: 157-6-02-01

## Conclusion

The Super Expander II Rev. 1 is fully functional

Pos. Qty Value Footprint Ref.-No. Comment

1 1 157-2-01-01 2 Layer PCB Rev. 1 2 layer, Cu 35µ, HASL, 102.0mm x 75.0mm, 1.6mm FR4

8 100n C-2,5 C1, C2, C3, C4, C5, C7, C8,

C9

Ceramic capacitor, pitch 2.5mm (25V or 50V)

1 100u/16V C07/2,5 C6 Electrolytic cap, pitch 2.5mm

3 10k R-10 R1, R2, R3 Metal fil resistor

6 2114 DIL18 IC3, IC4, IC5, IC6, IC7, IC8 1k x 4 Static RAM. Type 2114. AliExpress search term

"uPD2114". Or some retro computer stores like restore-

store.de

6 DIP18-Sockets (IC3), (IC4), (IC5), (IC6), (IC7),

(IC8)

optional

4 1x3 pin header (2.54mm

pitch)

COMBI-3P JP1, JP2, JP4, JP5 standard pin header (option, can be configured with solder

bridge)

1 3X2 pin header (2.54mm

pitch)

COMBI-3X2 JP3 standard pin header (option, can be configured with solder

bridge)

### 7 jumper 2.54mm (JP1), (JP2), (JP3), (JP4), (JP5) standard jumper. Refer to JP1-3 1 JTP-1130 JTP-1130 SW1 6 x 6 mm tact switch (standard)

### 1 M27C512-DIP28 DIL28-6 IC1 EPROM: 27C64, 27C128, 27C256 possible. Refere to

document 157-6-02-**

### 1 M27C512-DIP28 DIL28-6 IC2 option, not required for super expander

### 2 DIP28-Sockets (IC1), (IC2) option, refer to IC1 and IC2

## Commodore VIC-20: Super Expander II Rev. 1

## Bill of Material Rev. 1.0

VIC20_SExpII_BOM_v1_0.xlsx

Drafted by Sven Petersen Page 1 of 1

16.07.2021 15:41
Doc.No.: 157-5-01-01.0

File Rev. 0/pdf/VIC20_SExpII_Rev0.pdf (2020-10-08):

# Project Documentation

## Commodore VIC-20: Super Expander II

## Project number: 157

## Revision: 0

## Date: 15.09.2020

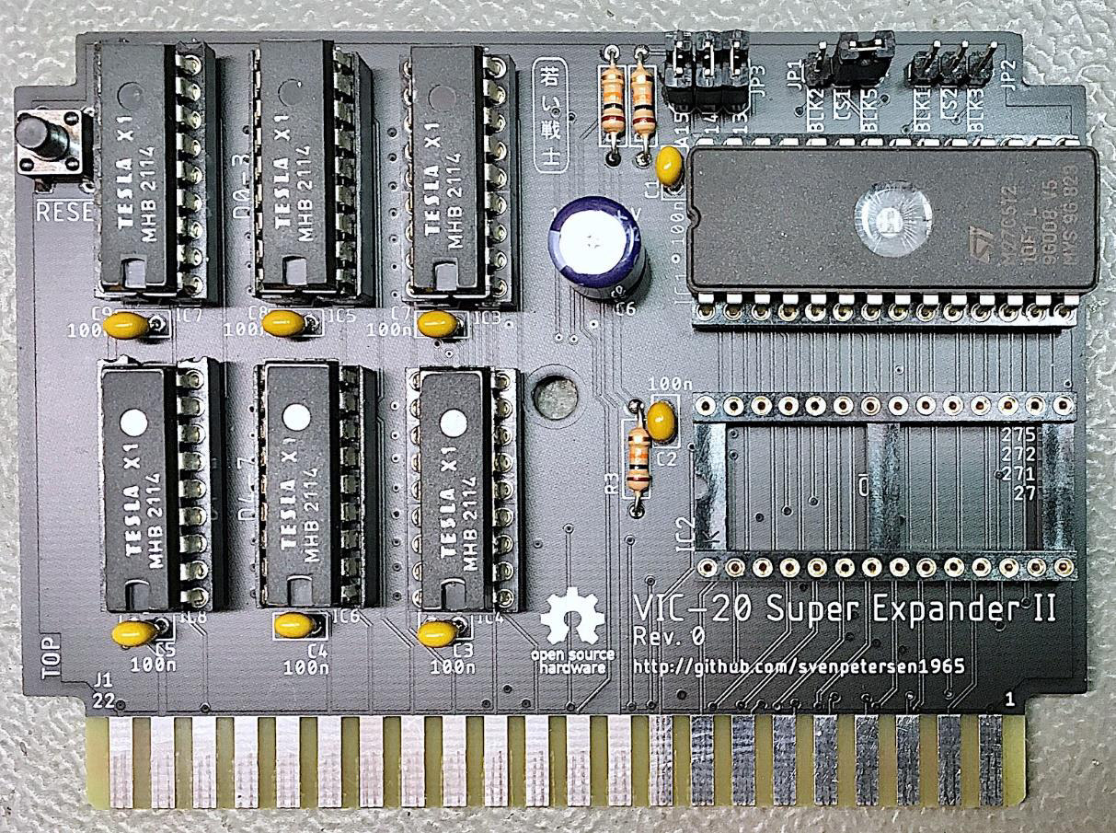
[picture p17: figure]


VIC20_SExpII_ModD.docx | | 08.10.2020 14:46
Drafted by Sven Petersen | Page 1 of 5 | Doc.-No.: 157-6-01-00

### Commodore VIC-20: Super Expander II Rev. 0

### Module Description

## General Description

The original Commodore VIC-1211A Super Expander is a Basic Extension, which contains high resolution graphics and sound commands and additional 3kB of RAM. It is a pretty versatile cartridge, which allows up to two 2364 ROMs, that can be configured to use either the 8k chip-selects /BLK2, /BLK5, /BLK1or /BLK3. The configuration is done with solder bridges.

Figure 1: The Commodore VIC-1211A Super Expander Cartridge

With less RAM (1k) and another software, the same PCB is used as a (Commodore) diagnostic cartridge for the VIC-20.

The disadvantage for own projects is the usage of 2364/2332 ROMs. Thus, the Super Expander II is a version of the original Super Expander cartridge that can fit up to two
27C512 EPROMs. The configuration is done with jumpers, which also work as solder bridges (no pin header required), in case the configuration is not desired to be changed.

Two of the chip-select signals apply to each EPROM. The 8k memory bank can be selected with three jumpers. The selection applies to both EPROMs.

The 2114 4x1k (static) RAMs are the same, like in the original Super Expander. They are still available from some retro computer stores for a comparatively good price and also from
AliExpress (search term “upd2114”).

VIC20_SExpII_ModD.docx | | 08.10.2020 14:46
Drafted by Sven Petersen | Page 2 of 5 | Doc.-No.: 157-6-01-00

## Configuration

### Chip selects

EPROM | Jumper | Chip Select | VIC-20 Address
IC1 | JP1 | BLK2 | $4000 - $5FFF
| | BLK5 | $A000 - $BFFF
IC2 | JP2 | BLK1 | $2000 - $3FFF
| | BLK3 | $6000 - $7FFF

Table 1: Configurable Chip Selects

### RAM Address

RAM | Chip Select | VIC-20 Address
IC3 (bit 0-3) IC4 (bit 4-7) | RAM1 | $0400 - $07FF
IC5 (bit 0-3) IC6 (bit 4-7) | RAM2 | $0800 - $0BFF
IC7 (bit 0-3) IC8 (bit 4-7) | RAM3 | $0C00 - $0FFF

Table 2: Mapping of the RAM ICs

### Memory Bank Select

There are two different types of addresses mentioned in this document:

- VIC-20 Address
- EPROM Offset Address

Both types must not be confused! The EPROM Offset Address is the address of the selected memory bank within (the program buffer of the EPROM). This is, where you load the different binary files to the EPROM buffer. One of those memory banks is selected with the Jumper JP3. This appears in/is mapped to the VIC-20 memory at the address determined by the chip select BLK1/2/3/5 (see Table 1).

JP3 | Address Bits | EPROM Address
A15 | A14 | A35 | A15 | A14 | A13 | (Offset)
SET | SET | SET | L | L | L | 0x0000 – 0x1FFF
SET | SET | OPEN | L | L | H | 0x2000 – 0x3FFF
SET | OPEN | SET | L | H | L | 0x4000 – 0x5FFF
SET | OPEN | OPEN | L | H | H | 0x6000 – 0x7FFF
OPEN | SET | SET | H | L | L | 0x8000 – 0x9FFF
OPEN | SET | OPEN | H | L | H | 0xA000 – 0xBFFF
OPEN | OPEN | SET | H | H | L | 0xC000 – 0xDFFF
OPEN | OPEN | OPEN | H | H | H | 0xE000 – 0xFFFF
Table 3: 8k cartridges memory banks

VIC20_SExpII_ModD.docx | | 08.10.2020 14:46
Drafted by Sven Petersen | Page 3 of 5 | Doc.-No.: 157-6-01-00

## EPROMs

Four different types/sizes of EPROMs can be used with the Super Expander II, not all settings make sense with them. Their pin out is shown in Table 4.

The effect of the settings and the recommended configurations are shown in Table 5.

27C64
| 27C128
| 27C256
| 27C512
| SOCKET
Vpp | Vpp | Vpp | A15 | 1 | A15 | VCC | 28 | VCC | VCC | VCC | VCC
A12 | A12 | A12 | A12 | 2 | A12 | A14 | 27 | A14 | A14 | /PGM | /PGM
A7 | A7 | A7 | A7 | 3 | A7 | A13 | 26 | A13 | A13 | A13 | n.c.
A6 | A6 | A6 | A6 | 4 | A6 | A8 | 25 | A8 | A8 | A8 | A8
A5 | A5 | A5 | A5 | 5 | A5 | A9 | 24 | A9 | A9 | A9 | A9
A4 | A4 | A4 | A4 | 6 | A4 | A11 | 23 | A11 | A11 | A11 | A11
A3 | A3 | A3 | A3 | 7 | A3 | /OE | 22 | /G/Vpp | /G | /G | /G
A2 | A2 | A2 | A2 | 8 | A2 | A10 | 21 | A10 | A10 | A10 | A10
A1 | A1 | A1 | A1 | 9 | A1 | GND | 20 | /E | /E | /E | /E
A0 | A0 | A0 | A0 | 10 | A0 | D7 | 19 | D7 | D7 | D7 | D7
D0 | D0 | D0 | D0 | 11 | D0 | D6 | 18 | D6 | D6 | D6 | D6
D1 | D1 | D1 | D1 | 12 | D1 | D5 | 17 | D5 | D5 | D5 | D5
D2 | D2 | D2 | D2 | 13 | D2 | D4 | 16 | D4 | D4 | D4 | D4
GND | GND | GND | GND | 14 | GND | D3 | 15 | D3 | D3 | D3 | D3
Table 4: EPROM pin compatibility
EPROM | Size | A15 | A14 | A13
27C512 | 64kx8 | yes | yes | yes
27C256 | 32kx8 | HIGH | yes | yes
27C128 | 16kx8 | HIGH | HIGH | yes
27C64 | 8kx8 | HIGH | HIGH | HIGH
Table 5: Settings per EPROM type

In case Vpp is located at a dedicated pin (pin 1), A15 has no effect anymore. A HIGH level is recommended (switch is off). The /PGM Pin should be set HIGH. The n.c. (not connected) pin should be HIGH (with pull-up resistor) or open.

VIC20_SExpII_ModD.docx | | 08.10.2020 14:46
Drafted by Sven Petersen | Page 4 of 5 | Doc.-No.: 157-6-01-00

## Using parallel EEPROMs

There are parallel EPROMs, which fit into the EPROM sockets. They do not require erasing with a UV eraser, like EPROMs, but the price is higher.

Since they can be written, which is controlled by the WE signal, but the Super Expander II cartridge is lacking of this functionality, this signal has to be HIGH (inactive). The 28C256 has the A14 signal connected to Pin 1, which is A15 of the EEPROM socket. This is no problem, but it has to be kept in mind, that the jumper for A15 has effect on the bank select A14 of the EPROM.

28C64
| 28C256
| SOCKET
n.c. | A14 | 1 | A15 | VCC | 28 | VCC | VCC
A12 | A12 | 2 | A12 | A14 | 27 | /WE | /WE
A7 | A7 | 3 | A7 | A13 | 26 | A13 | n.c
A6 | A6 | 4 | A6 | A8 | 25 | A8 | A8
A5 | A5 | 5 | A5 | A9 | 24 | A9 | A9
A4 | A4 | 6 | A4 | A11 | 23 | A11 | A11
A3 | A3 | 7 | A3 | /OE | 22 | /G/Vpp | /OE
A2 | A2 | 8 | A2 | A10 | 21 | A10 | A10
A1 | A1 | 9 | A1 | GND | 20 | /E | /CE
A0 | A0 | 10 | A0 | D7 | 19 | D7 | D7
D0 | D0 | 11 | D0 | D6 | 18 | D6 | D6
D1 | D1 | 12 | D1 | D5 | 17 | D5 | D5
D2 | D2 | 13 | D2 | D4 | 16 | D4 | D4
GND | GND | 14 | GND | D3 | 15 | D3 | D3
Table 6: EEPROM pin compatibility
EEPROM | Size | A15 | A14 | A13
28C256 | 32kx8 | =A14 | OPEN | yes
28C64 | 8kx8 | OPEN | OPEN | OPEN
Table 7: Settings per EEPROM type

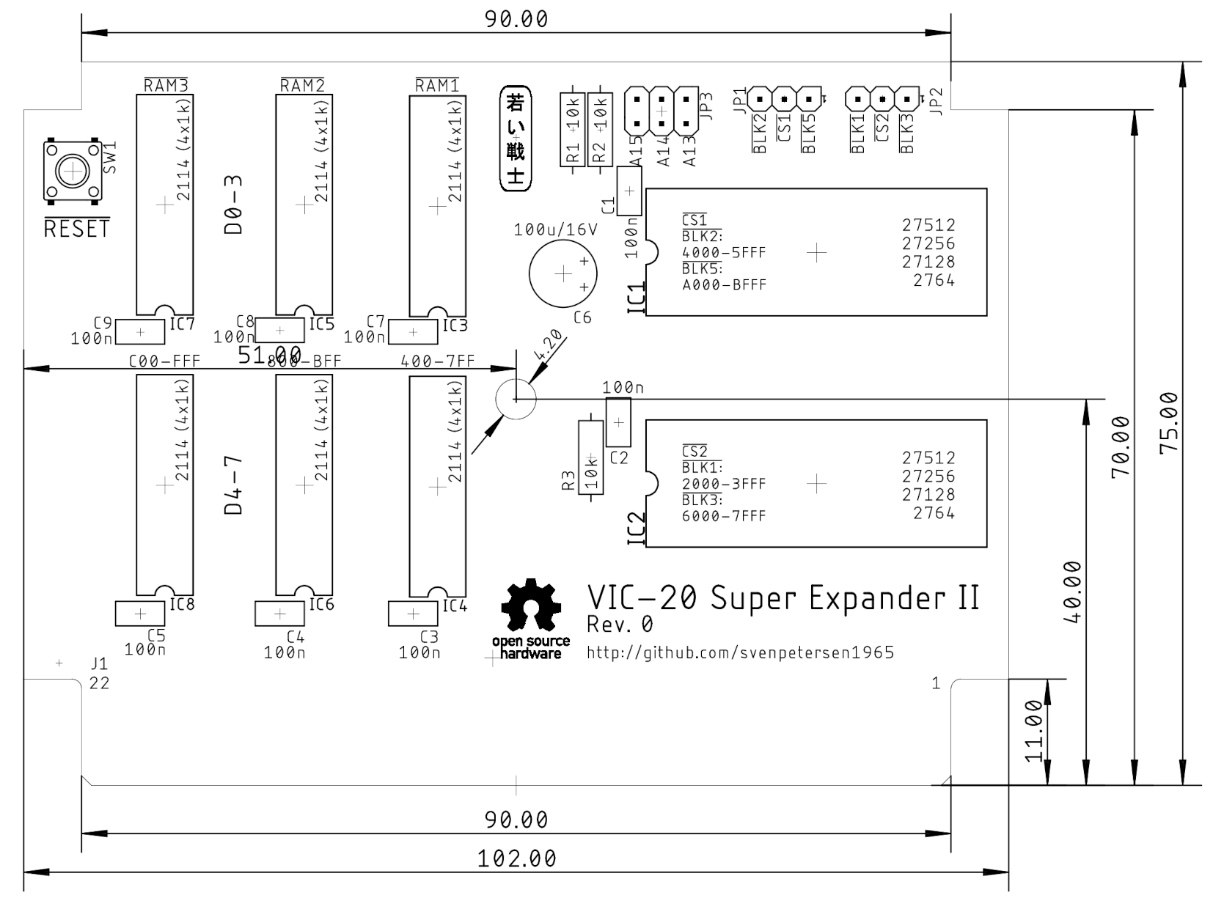
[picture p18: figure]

VIC20_SExpII_ModD.docx | | 08.10.2020 14:46
Drafted by Sven Petersen | Page 5 of 5 | Doc.-No.: 157-6-01-00

## Dimensions

The dimensions of the Super Expander II are identical to those of the original super Expander PCB.

Figure 2: Dimensions of the Super Expander II

The PCB fits the original super Expander cartridge case, another VIC-20 cartridge case from Commodore or the tfw8bit.com cartridge case.

The VIC-20 cartridge cases are high enough to fits the Super Expander II PCB even with the ICs on sockets and vertical jumpers. This has been verified for the Super Expander case and the tfw8bit

### case. The tfw8bit case and the “other Commodore VIC-20” cases require two T-shaped board

supports in the middle of the lower shell to be removed.

## Revision History

### Rev. 0

- Prototype: Fully functional.

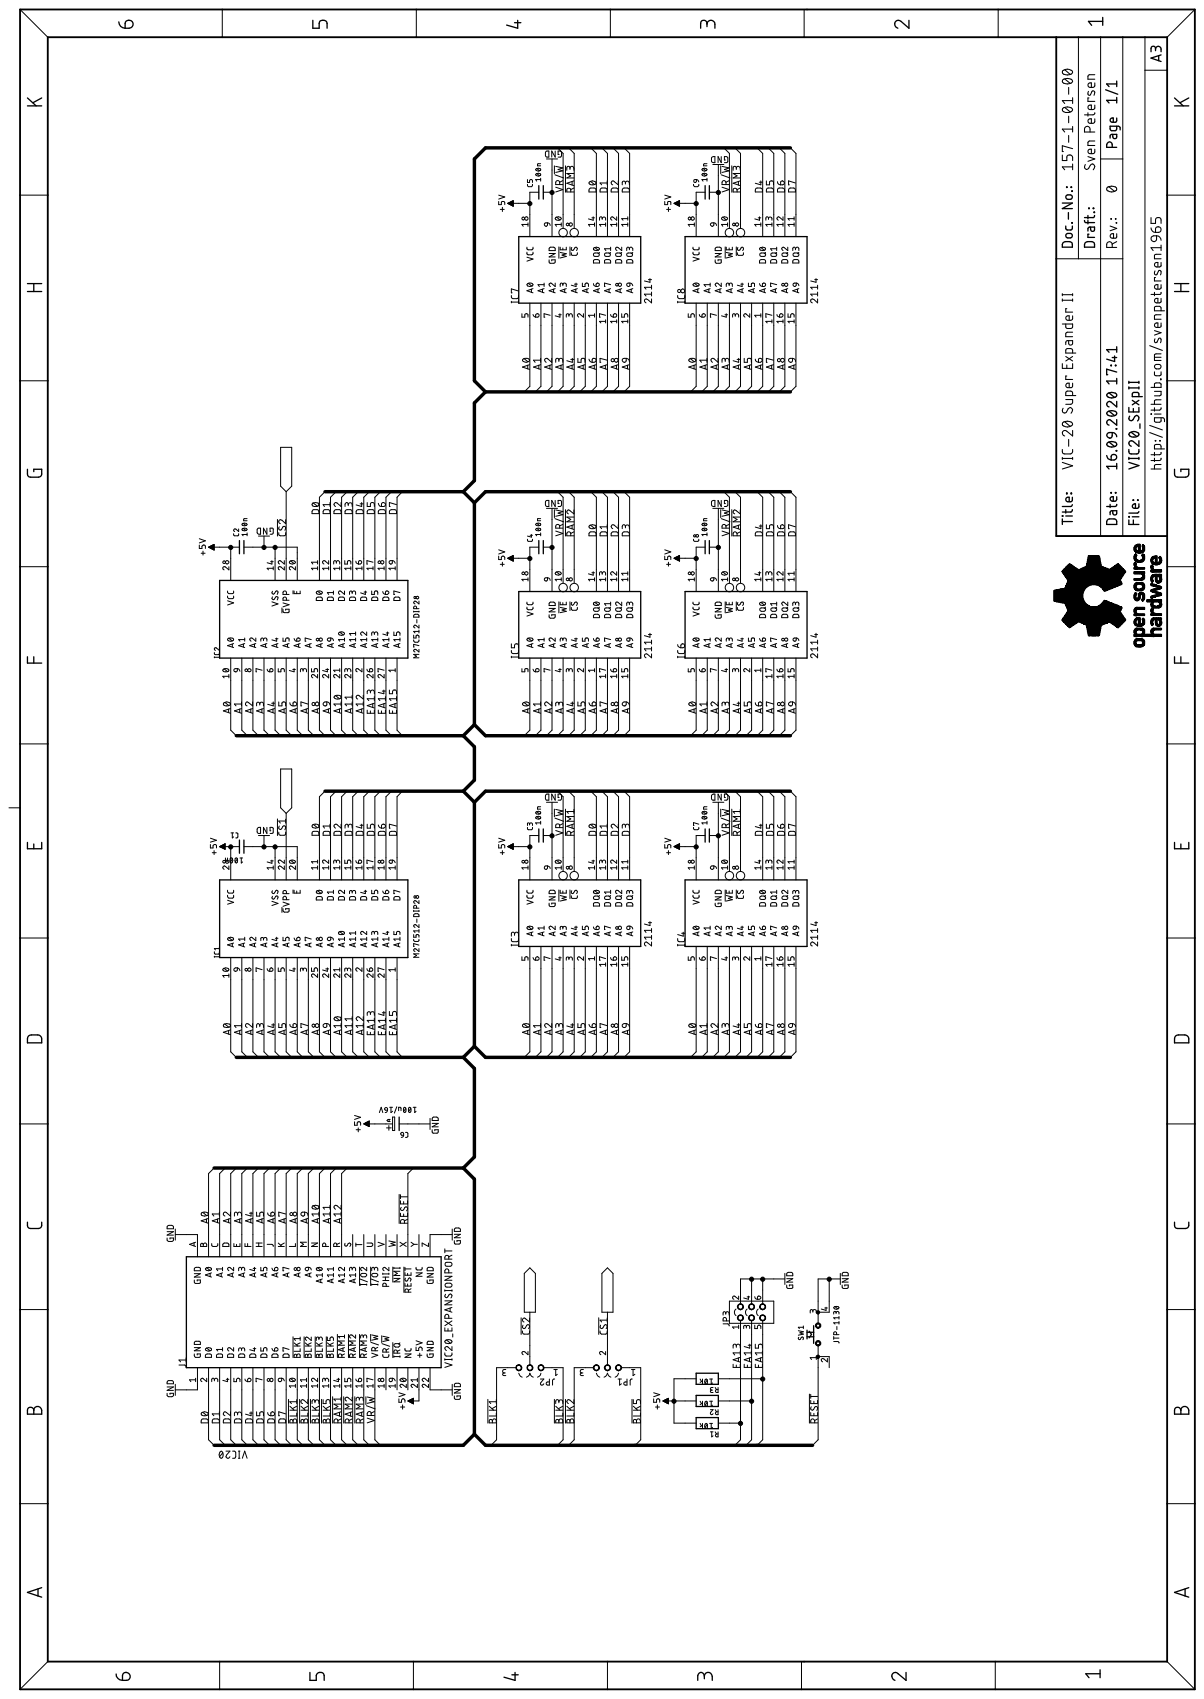
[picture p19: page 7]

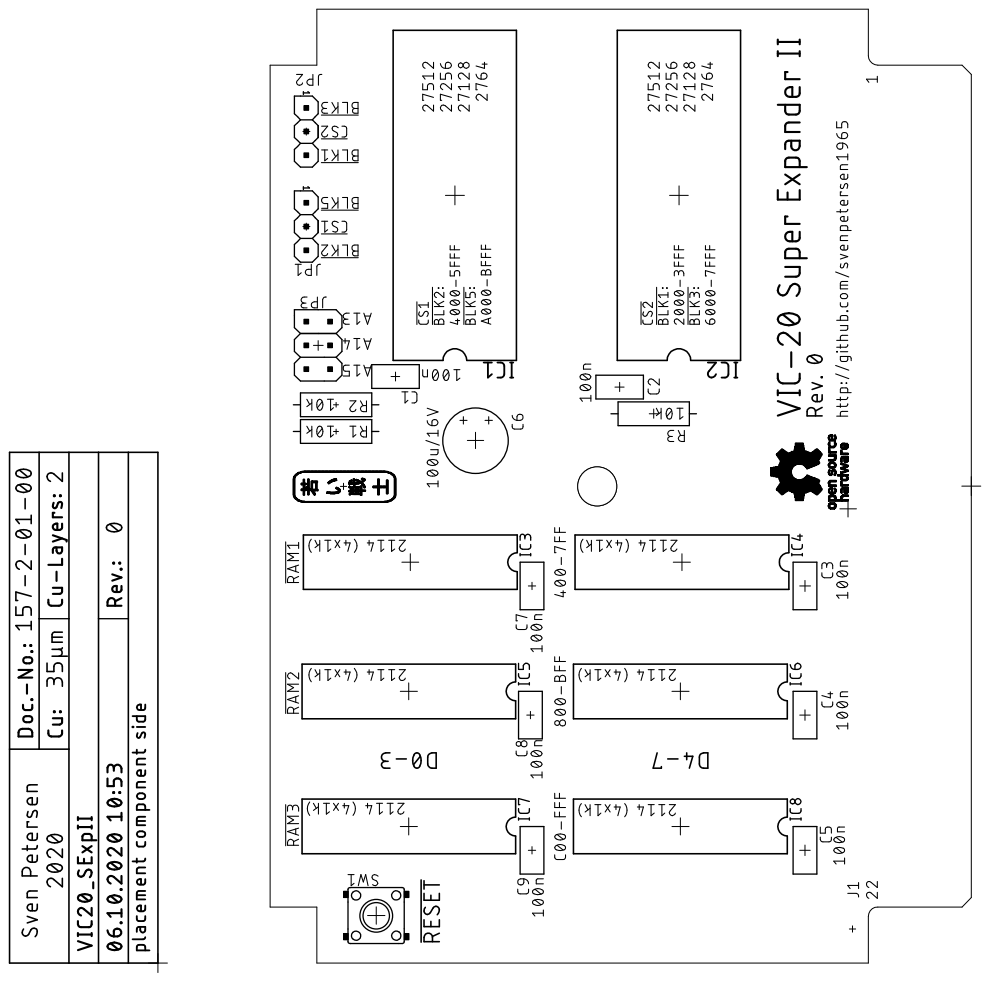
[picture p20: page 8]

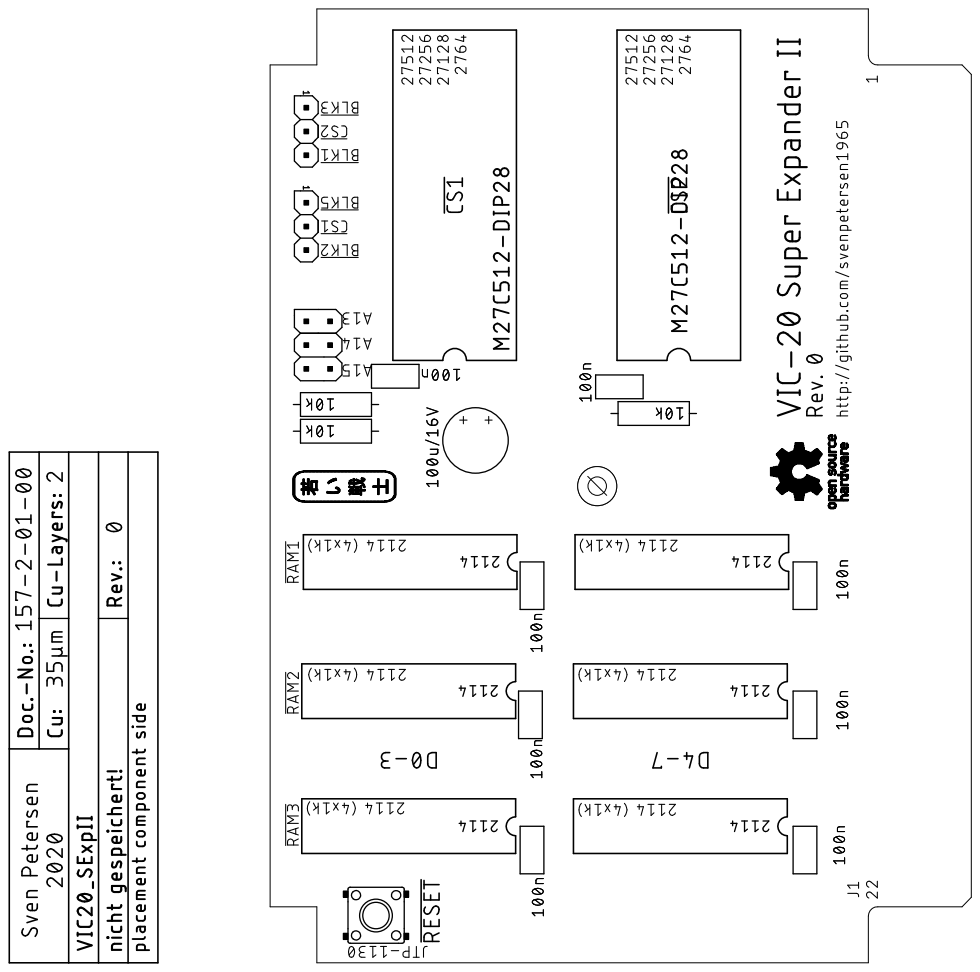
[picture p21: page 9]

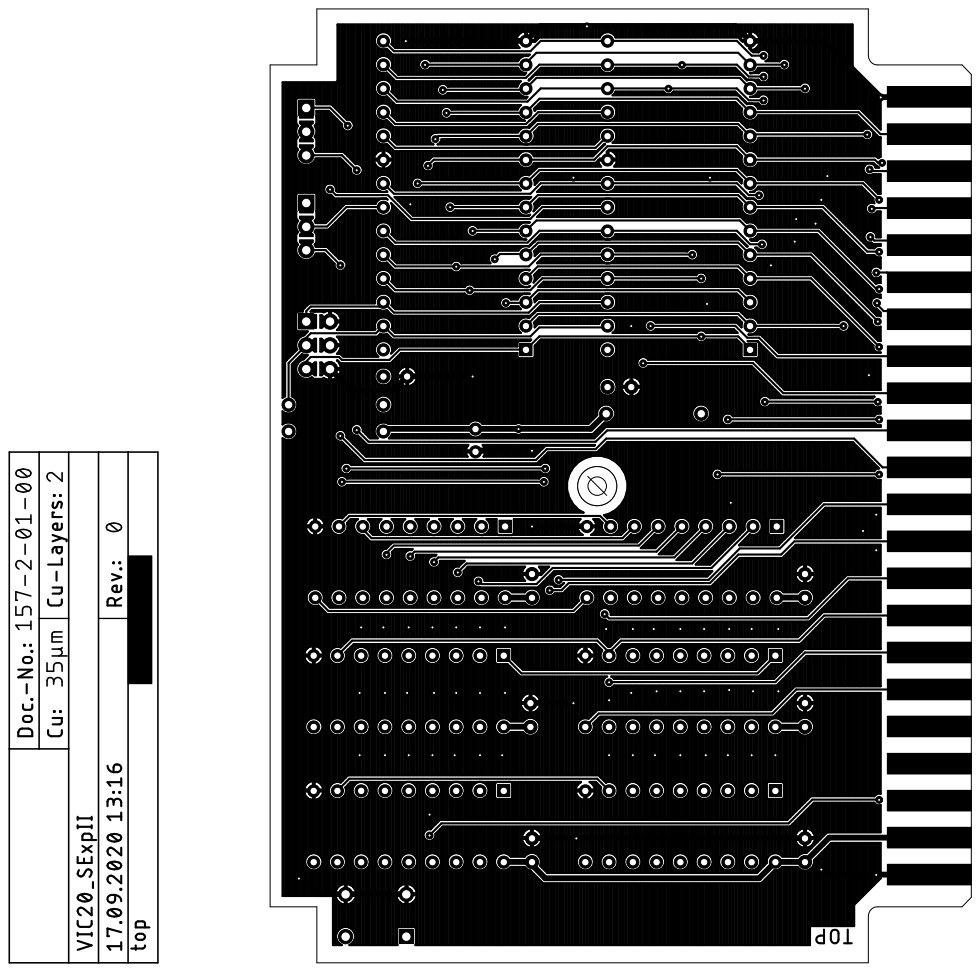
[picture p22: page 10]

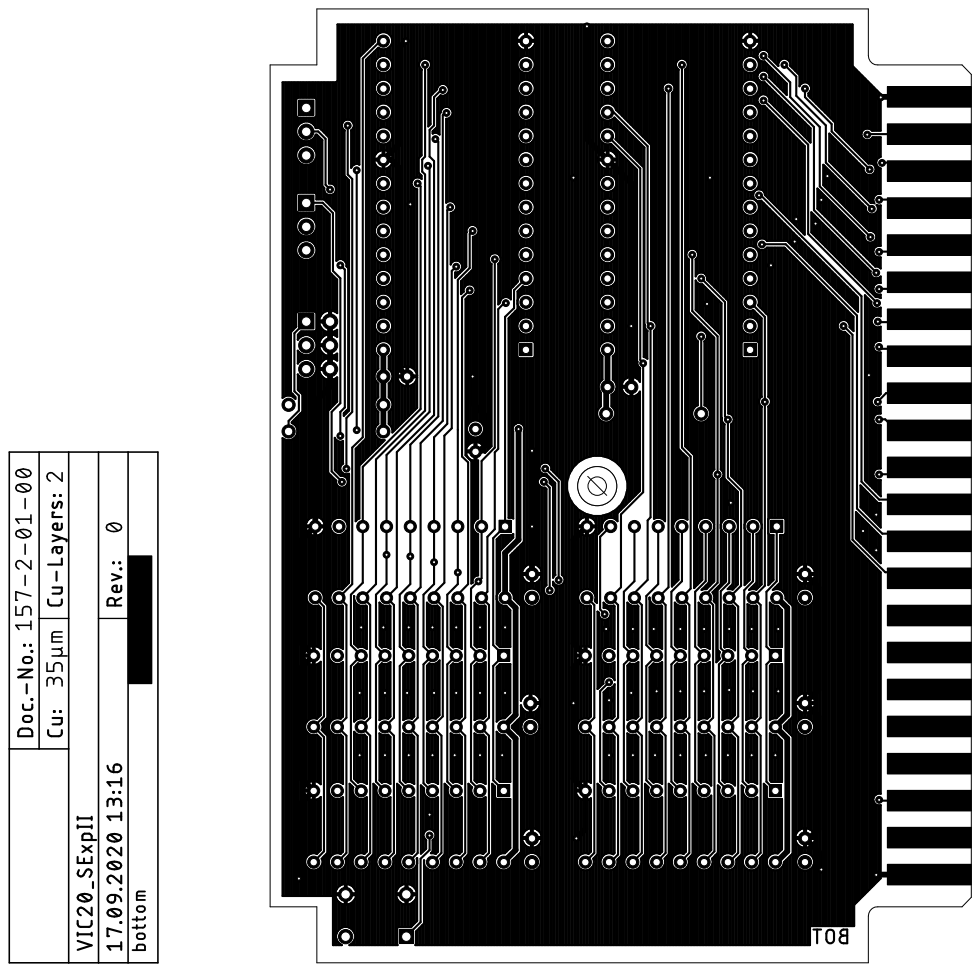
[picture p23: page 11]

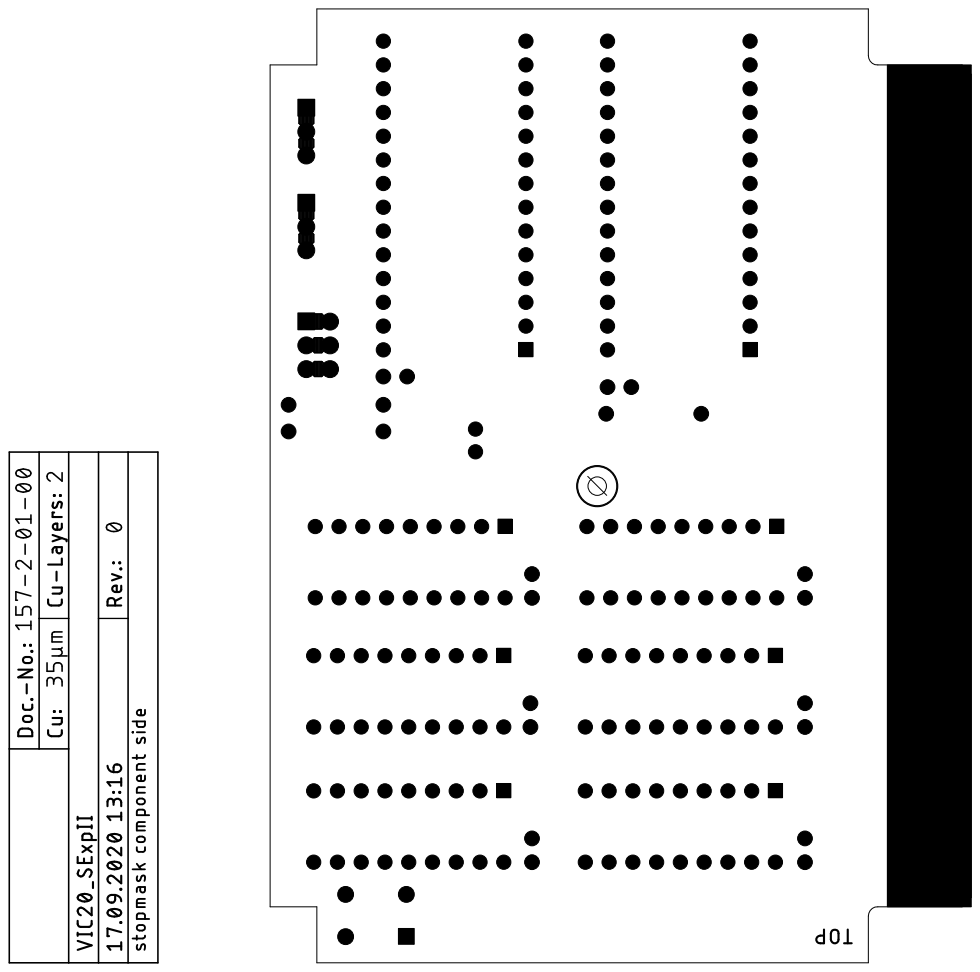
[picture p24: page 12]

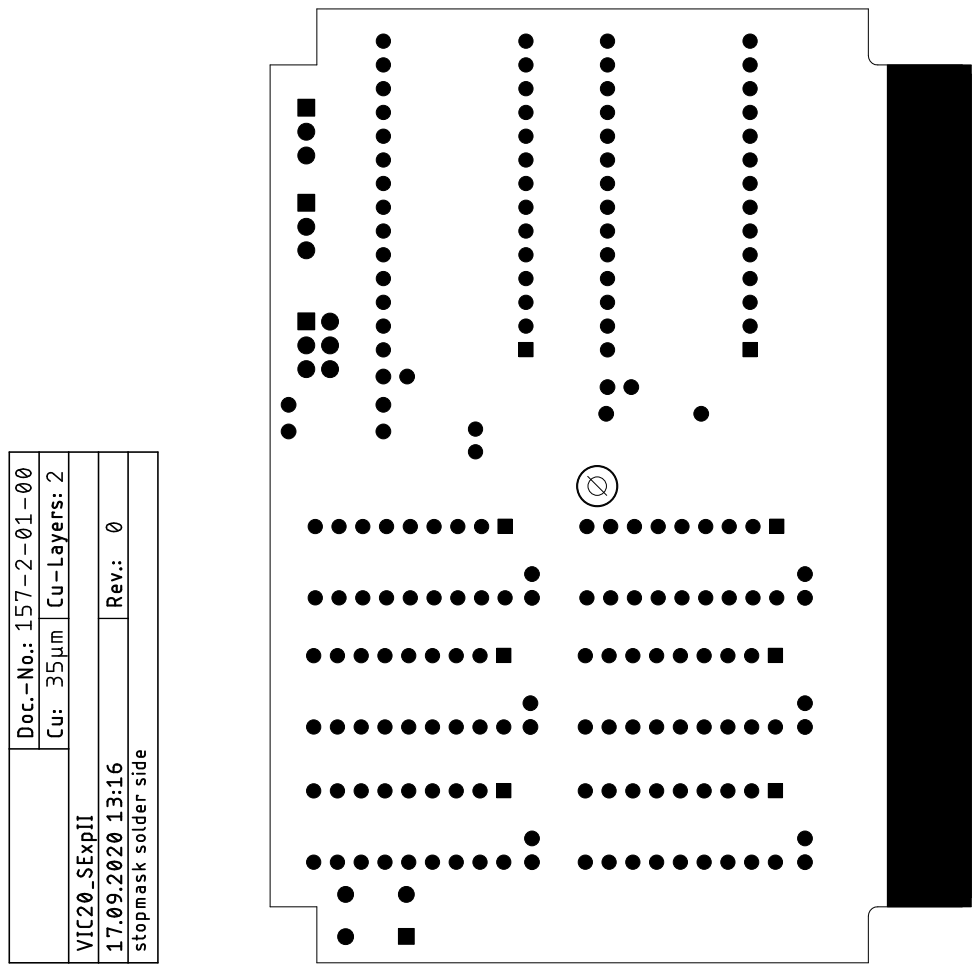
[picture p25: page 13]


VIC20_SExpII_Test.docx | | 08.10.2020 14:46
Drafted by Sven Petersen | Page 1 of 2 | Doc.-No.: 157-6-02-00

### Commodore VIC-20: Super Expander II Rev. 0

### Testing

## Test Setup

The tests were conducted with a VIC-20 (ASSY 250403 Rev. D) and a Super Expander II cartridge (Rev. 0) with 3k of RAM (6 pcs of TESLA MHB 2114) and up to two 27C512 EPROMs.

## Test Execution

### Super Expander Software

First, the original Super Expander Software from zimmers.net and the VIC-MON for $B000 were programed to an EPROM. These two programs fit into one 8k memory bank, since the Super Expander software is a 4k software. The EPROM was inserted the in IC1 socket and CS1 (JP1) was

set to BLK5 ($A000-$BFFF).

The cartridge was inserted into the VIC-20 and the computer was switched on. It booted normally and 6519 Bytes Free were reported. The Super Expander requires bytes in RAM, so this is correct.

The function keys produce some of the additional Super Expander instructions. A short program, which is using those instructions, was executed successfully.

✓ Function of RAM and EPROM IC1 with BLK5 and the Super Expander Software verified.

SYS11*4096 (which is $B000) started the VIC-MON.

✓ Additional test.

### RESET Button

The RESET button (SW1) was pressed. The VIC-20 rebooted properly.

✓ RESET button verified

### VIC-20 Diagnostic Software

The software (PAL) also origins from zimmers.net. It was programmed into the 2nd 8k of the said EPROM, a different version of this software (NTSC) was programmed to the 3rd 8k.

The jumpers on JP3 were set to the 2nd 8k (A15..13: set set open), JP1 remained at BLK5 .

All RAM except the lowest 1k (IC3/4) was removed.

The diagnostics software started and executed properly (together with the VIC-20 diagnostics harness). For the 2nd version of the diagnostic software, JP3 was set to the 3rd 8k bank (A15..13: set open set). This software executed properly, too.

✓ Bank select (000, 001, 010) on JP3 verified

### Game Cartridge Donkey Kong

This game is a 16k game and requires both EPROMs.
The software for $A000 was programmed in a fresh EPROM, which was inserted into IC1. JP1 remained at BLK5 . The other part of the software, which is located at $2000 was programmed

VIC20_SExpII_Test.docx | | 08.10.2020 14:46
Drafted by Sven Petersen | Page 2 of 2 | Doc.-No.: 157-6-02-00

into another fresh EPROM, which was then inserted into the IC2 socket. JP2 was set to BLK1 . All jumpers on JP3 were set.

The software started properly and the game could be played.

✓ EPROM IC2 with BLK1 verified

### Game Cartridge AE

The software origins from zimmers.net. It consisted of two images, one for $A000 and one for $6000. The images were programmed into two EPROMs, the $A000 software was inserted into IC1, the $6000 software into IC2. Jumper JP1 was set to BLK5 , JP2 to BLK3 . The software started properly and the game could be played.

✓ EPROM IC2 with BLK3 verified

### VIC-MON (for $4000)

The source of this software is once again zimmers.net. It was programmed into the 5th 8k memory bank (@ buffer address $8000) of an EPROM. The EPROM was inserted into IC1 and JP1 was set to BLK2 .

SYS4x1022 started the software properly.

✓ Bank select (100) on JP3 and BLK2 (JP1) verified

### Installation in cartridge cases

The fully assembled Super Expander II PCB (all ICs on sockets and all vertical jumpers) was installed in the original Commodore Super Expander cartridge case- This could be accomplished without a problem.

The original Commodore Game cartridge case required removing some support structures for small PCBs, after that, it also fit.

The tfw8bit.com VIC-20 cartridge case fits after removing the support structures for the short PCBs.

✓ Dimensions verified

## Conclusion

The Super Expander II Rev. 0 is fully functional

Pos. Qty Value Footprint Ref.-No. Comment

1 1 157-2-01-00 2 Layer PCB Rev. 0 2 layer, Cu 35µ, HASL, 102.0mm x 75.0mm, 1.6mm FR4

8 100n C-2,5 C1, C2, C3, C4, C5, C7, C8,

C9

Ceramic capacitor, pitch 2.5mm (25V or 50V)

1 100u/16V C07/2,5 C6 Electrolytic cap, pitch 2.5mm

3 10k R-10 R1, R2, R3 Metal fil resistor

6 2114 DIL18 IC3, IC4, IC5, IC6, IC7, IC8 1k x 4 Static RAM. Type 2114. AliExpress search term

"uPD2114". Or some retro computer stores like restore-

store.de

6 DIP18-Sockets (IC3), (IC4), (IC5), (IC6), (IC7),

(IC8)

optional

2 1x3 pin header (2.54mm

pitch)

COMBI-3P JP1, JP2 standard pin header (option, can be configured with solder

bridge)

1 3X2 pin header (2.54mm

pitch)

COMBI-3X2 JP3 standard pin header (option, can be configured with solder

bridge)

### 5 jumper 2.54mm (JP1), (JP2), (JP3) standard jumper. Refer to JP1-3 1 JTP-1130 JTP-1130 SW1 6 x 6 mm tact switch (standard)

### 1 M27C512-DIP28 DIL28-6 IC1 EPROM: 27C64, 27C128, 27C256 possible. Refere to

document 157-6-02-**

### 1 M27C512-DIP28 DIL28-6 IC2 option, not required for super expander

### 2 DIP28-Sockets (IC1), (IC2) option, refer to IC1 and IC2

## Commodore VIC-20: Super Expander II Rev. 0

## Bill of Material Rev. 0.0

VIC20_SExpII_BOM_v0_0.xlsx

Drafted by Sven Petersen Page 1 of 1

08.10.2020 15:09
Doc.No.: 157-5-01-00.0

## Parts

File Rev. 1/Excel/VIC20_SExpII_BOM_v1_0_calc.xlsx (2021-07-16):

Commodore VIC-20: Super Expander II Rev. 1
Bill of Material Rev. 1.0
Pos. | Qty | Value | €/ea | € | Comment
1 | 1 | 157-2-01-00 | 1.00 € | 1.00 € | 2 layer, Cu 35µ, HASL, 102.0mm x 75.0mm, 1.6mm FR4
 | 8 | 100n | 0.20 € | 1.60 € | Ceramic capacitor, pitch 2.5mm (25V or 50V)
 | 1 | 100u/16V | 0.22 € | 0.22 € | Electrolytic cap, pitch 2.5mm
 | 3 | 10k | 0.08 € | 0.24 € | Metal fil resistor
 | 6 | 2114 | 1.66 € | 9.96 € | 1k x 4 Static RAM. Type 2114. AliExpress search term "uPD2114". Or some retro computer stores like restore-store.de
 | 6 | DIP18-Sockets | 0.32 € | 1.92 € | optional
 | 4 | 1x3 pin header (2.54mm pitch) | 0.07 € | 0.28 € | standard pin header (option, can be configured with solder bridge)
 | 1 | 3X2 pin header (2.54mm pitch) | 0.14 € | 0.14 € | standard pin header (option, can be configured with solder bridge)
 | 7 | jumper 2.54mm | 0.02 € | 0.14 € | standard jumper. Refer to JP1-3
 | 1 | JTP-1130 | 0.15 € | 0.15 € | 6 x 6 mm tact switch (standard)
 | 1 | M27C512-DIP28 | 5.50 € | 5.50 € | EPROM: 27C64, 27C128, 27C256 possible. Refere to document 157-6-02-**
 | 1 | M27C512-DIP28 | 0.00 € | 0.00 € | option, not required for super expander
 | 1 | DIP28-Sockets | 0.42 € | 0.42 € | option, refer to IC1 and IC2
 |  | Total |  | 21.57 €

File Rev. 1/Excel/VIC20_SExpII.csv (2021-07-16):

Qty | Value | Device | Package | Parts | Description
8 | 100n | CAP01 | C-2,5 | C1, C2, C3, C4, C5, C7, C8, C9
1 | 100u/16V | C07/2,5 | C07/2,5 | C6
3 | 10k | RES04 | R-10 | R1, R2, R3
6 | 2114 | 2114 | DIL18 | IC3, IC4, IC5, IC6, IC7, IC8
4 | COMBI-3P | COMBI-3P | COMBI-3P | JP1, JP2, JP4, JP5
1 | COMBI-3X2P | COMBI-3X2P | COMBI-3X2 | JP3
1 | JPT1236HB | JPT1236HB | JTP_1236HB | SW1
2 | M27C512-DIP28 | M27C512-DIP28 | DIL28-6 | IC1, IC2
1 | OPEN_SOURCE_HW | OPEN_SOURCE_HW | OPENHW | U$2
1 | VIC20_EXPANSIONPORT | VIC20_EXPANSIONPORT | VIC20_EXPANSION | J1

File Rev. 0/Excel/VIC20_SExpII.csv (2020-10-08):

Qty | Value | Device | Package | Parts | Description
8 | 100n | CAP01 | C-2,5 | C1, C2, C3, C4, C5, C7, C8, C9
1 | 100u/16V | C07/2,5 | C07/2,5 | C6
3 | 10k | RES04 | R-10 | R1, R2, R3
6 | 2114 | 2114 | DIL18 | IC3, IC4, IC5, IC6, IC7, IC8
2 | COMBI-3P | COMBI-3P | COMBI-3P | JP1, JP2
1 | COMBI-3X2P | COMBI-3X2P | COMBI-3X2 | JP3
1 | JTP-1130 | JTP-1130 | JTP-1130 | SW1
2 | M27C512-DIP28 | M27C512-DIP28 | DIL28-6 | IC1, IC2
1 | OPEN_SOURCE_HW | OPEN_SOURCE_HW | OPENHW | U$2
1 | VIC20_EXPANSIONPORT | VIC20_EXPANSIONPORT | VIC20_EXPANSION | J1

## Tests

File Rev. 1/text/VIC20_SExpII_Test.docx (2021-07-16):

Commodore VIC-20: Super Expander II Rev. 1

Testing

# Test Setup

The tests were conducted with a VickyTwenty (Reproduction of ASSY 250403 Rev. D) and a Super Expander II cartridge (Rev. 1) with 3k of RAM (6 pcs of National Semiconductor MM2114N) and up to two (ST) 27C512 EPROMs (120ns).

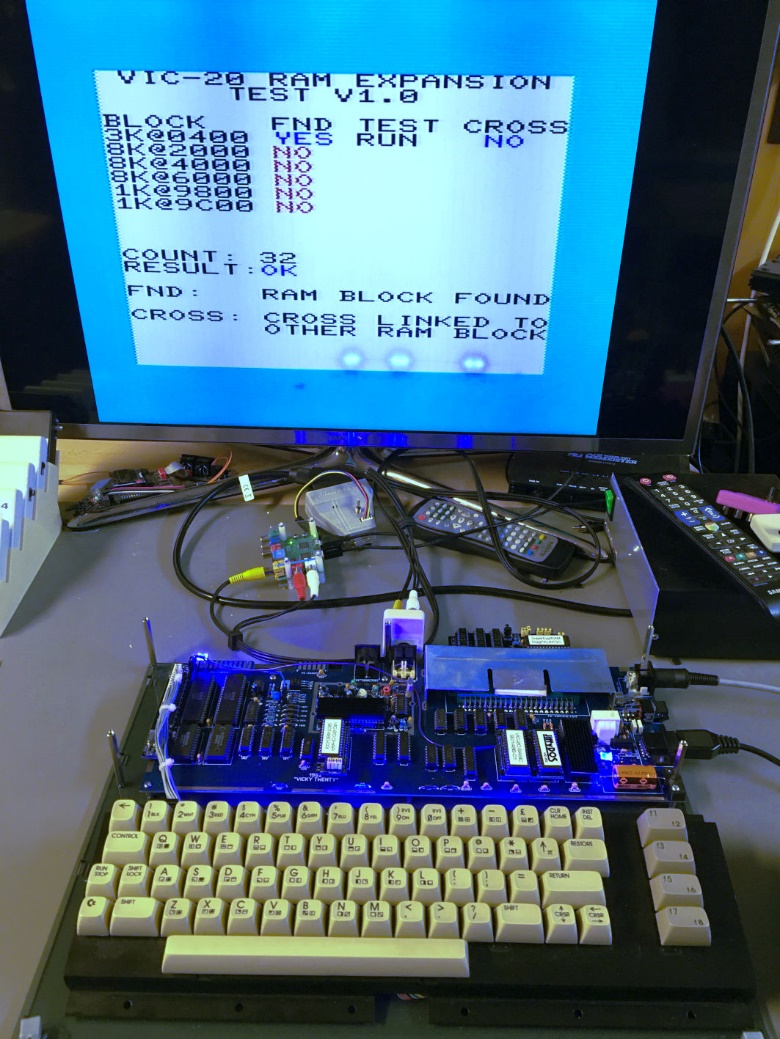
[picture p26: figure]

Figure 1: Test Setup

# Test Execution

## Super Expander Software

First, the original Super Expander Software from zimmers.net and the Commodore VICMON for $B000 were programed to an EPROM. These two programs fit into one 8k memory bank, since the Super Expander software is a 4k software. The EPROM was inserted the in IC1 socket and (JP1) was set to ($A000-$BFFF). The software size of 8k (for IC1) was set on JP4.

The cartridge was inserted into the VickyTwenty and the computer was switched on. It booted normally and 6519 Bytes Free were reported. The Super Expander requires bytes in RAM, so this is correct.

The function keys produce some of the additional Super Expander instructions. A short program, which is using those instructions, was executed successfully.

- Function of RAM and EPROM IC1 with and the Super Expander Software verified.

SYS11*4096 (which is $B000) started the VICMON.

- Additional test.

The software size was configured to 4k (JP4). So, the VICMON was not visible anymore. The VIC-20 booted properly.

SYS11*4096 resulted in a software crash, which shows that the software size selection is working.

- Software size selection (4k/8k) for IC1 is working properly.

## RESET Button

The RESET button (SW1) was pressed. The VIC-20 rebooted properly.

- RESET button verified

## RAM Expansion Test software

The jumpers on JP3 were set to the 2nd 8k (A15..13: set/set/open), JP1 remained at .
The software was executed properly. The 3k RAM expansion was found. Over 10,000 test cycles were carried out properly.

- The bank selection on JP3 (001) works properly
- RAM works properly

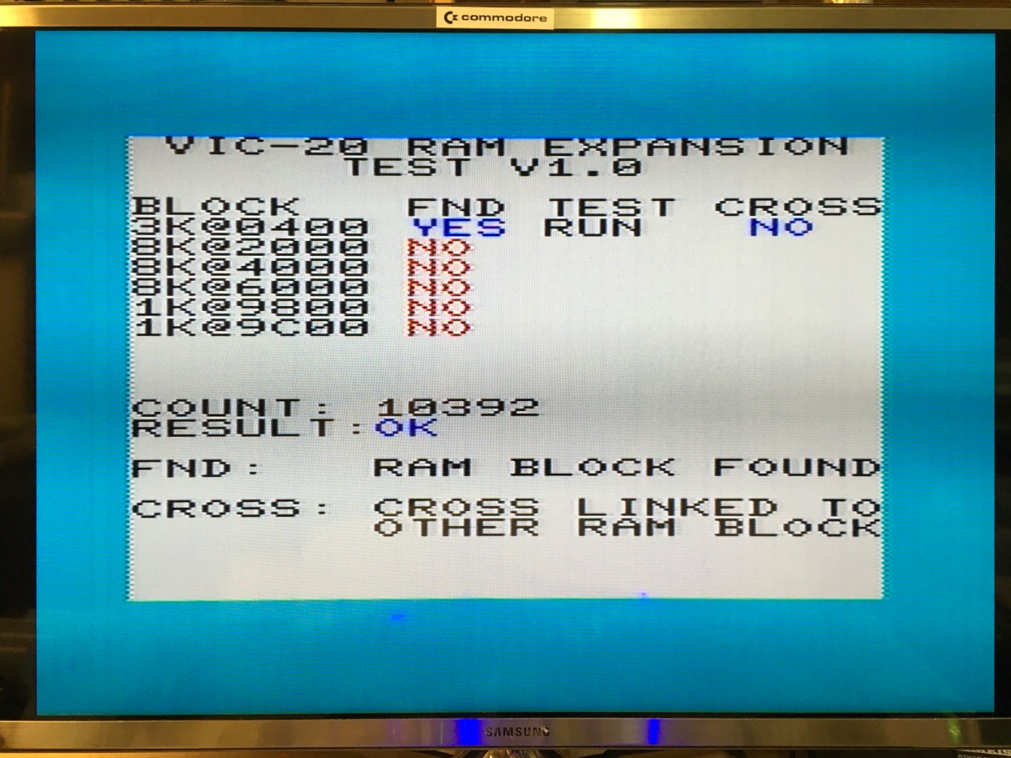
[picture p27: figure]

Figure 2: 3k RAM Expansion Test

## VIC-20 Diagnostic Software

The software (PAL) also origins from zimmers.net. It was programmed into the 2nd 8k of the said EPROM, a different version of this software (NTSC) was programmed to the 3rd 8k.

The jumpers on JP3 were set to the 3rd 8k (A15..13: set/open/set), JP1 remained at .

The diagnostics software started and executed properly (together with the VIC-20 diagnostics harness). For the 2nd version of the diagnostic software, JP3 was set to the 3rd 8k bank (A15..13: set/open/open). This software executed properly, too.

- Bank select (000, 001, 010, 011) on JP3 verified

## Game Cartridge Donkey Kong

This game is a 16k game and requires both EPROMs.
The software for $A000 was programmed in a fresh EPROM, which was inserted into IC1. JP1 remained at . The other part of the software, which is located at $2000 was programmed into another fresh EPROM, which was then inserted into the IC2 socket. JP2 was set to . All jumpers on JP3 were set.

The software started properly and the game could be played.

- EPROM IC2 with verified

## Game Cartridge AE

The software origins from zimmers.net. It consisted of two images, one for $A000 and one for $6000. The images were programmed into two EPROMs, the $A000 software was inserted into IC1, the $6000 software into IC2. Jumper JP1 was set to , JP2 to . The software started properly and the game could be played. The software size (JP4 and JP5) was set to 8k.

- EPROM IC2 with verified

## VIC-MON (for $4000)

The source of this software is once again zimmers.net. It was programmed into the 5th 8k memory bank (@ buffer address $8000) of an EPROM. The EPROM was inserted into IC1 and JP1 was set to .

SYS4x4096 started the software properly.

- Bank select (100) on JP3 and (JP1) verified

## Installation in cartridge cases

The fully assembled Super Expander II PCB (all ICs on sockets and all vertical jumpers) was installed in the original Commodore Super Expander cartridge case- This could be accomplished without a problem.

The original Commodore Game cartridge case required removing some support structures for small PCBs, after that, it also fit.

The tfw8bit.com VIC-20 cartridge case fits after removing the support structures for the short PCBs.

- Dimensions verified

# Conclusion

The Super Expander II Rev. 1 is fully functional

VIC20_SExpII_Test.docx 16.07.2021 16:09 Drafted by Sven Petersen Page 2 of 2 Doc.-No.: 157-6-02-01

VIC20_SExpII_Test.docx 16.07.2021 16:09 Drafted by Sven Petersen Page 1 of 1 Doc.-No.: 000-6-00-00

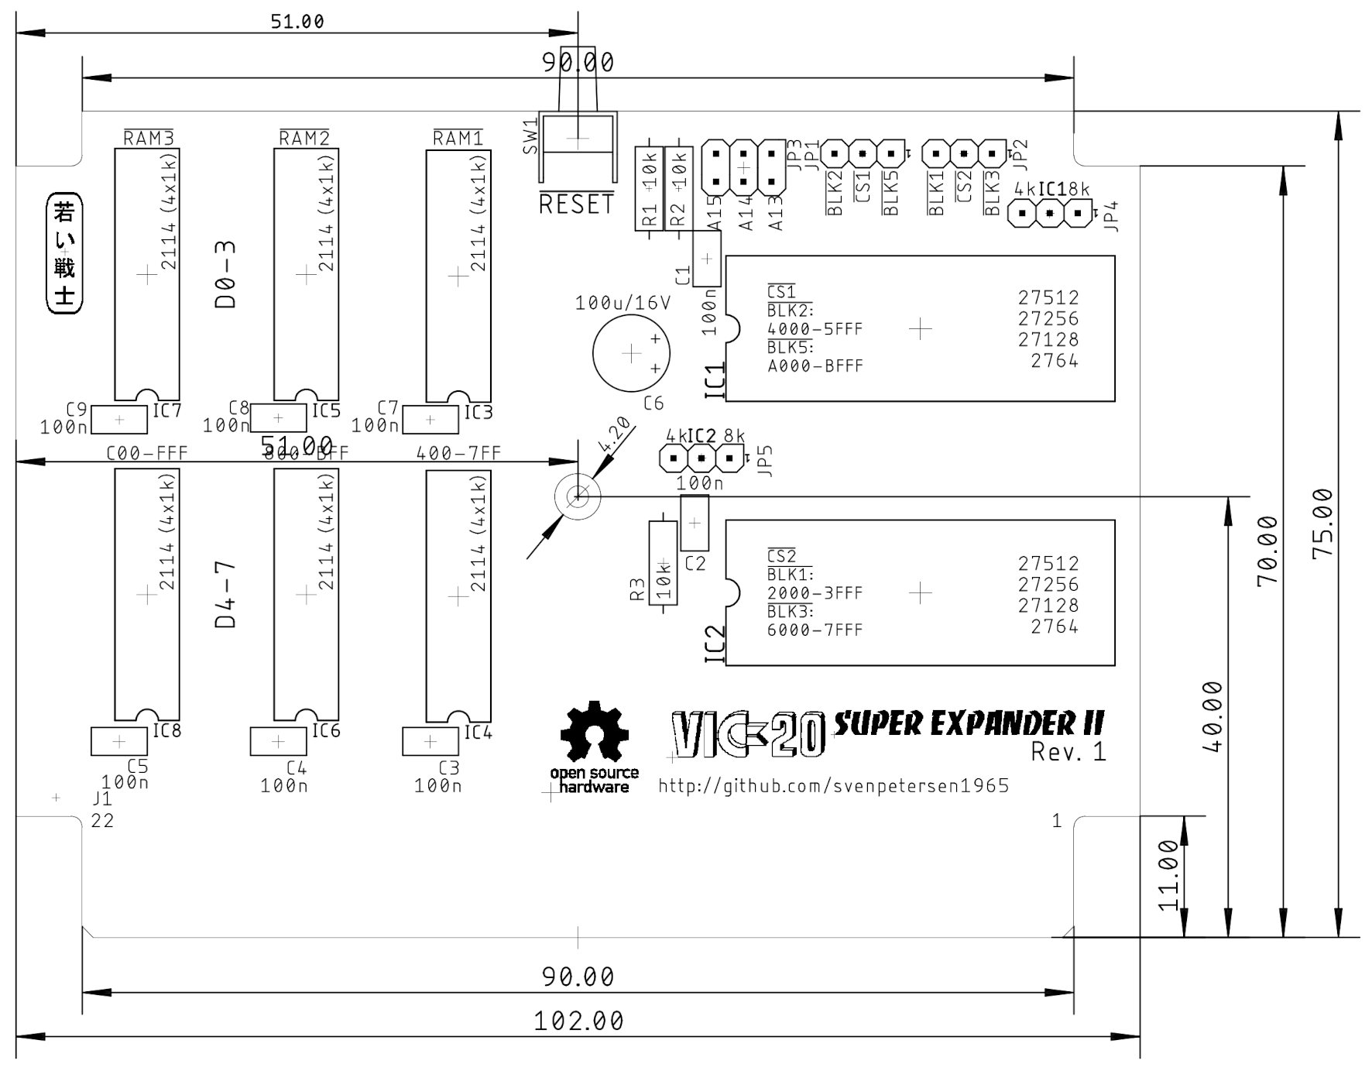
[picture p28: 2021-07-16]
Rev. 1/pictures/VIC20_SExpII_measures.png

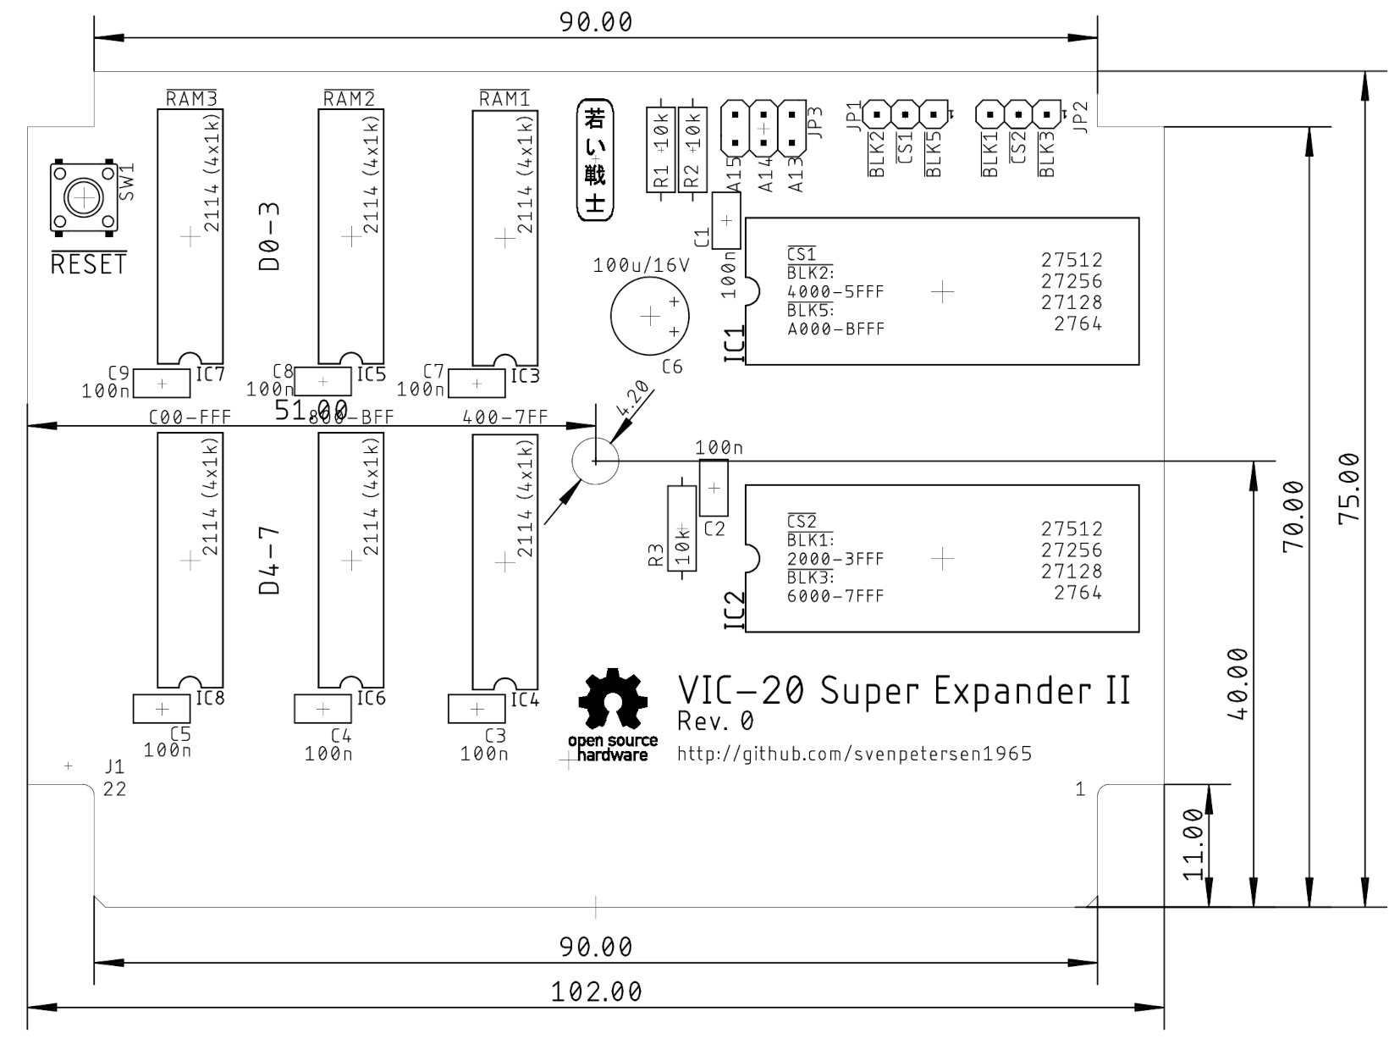
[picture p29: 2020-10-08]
Rev. 0/pictures/VIC20_SExpII_measures.png

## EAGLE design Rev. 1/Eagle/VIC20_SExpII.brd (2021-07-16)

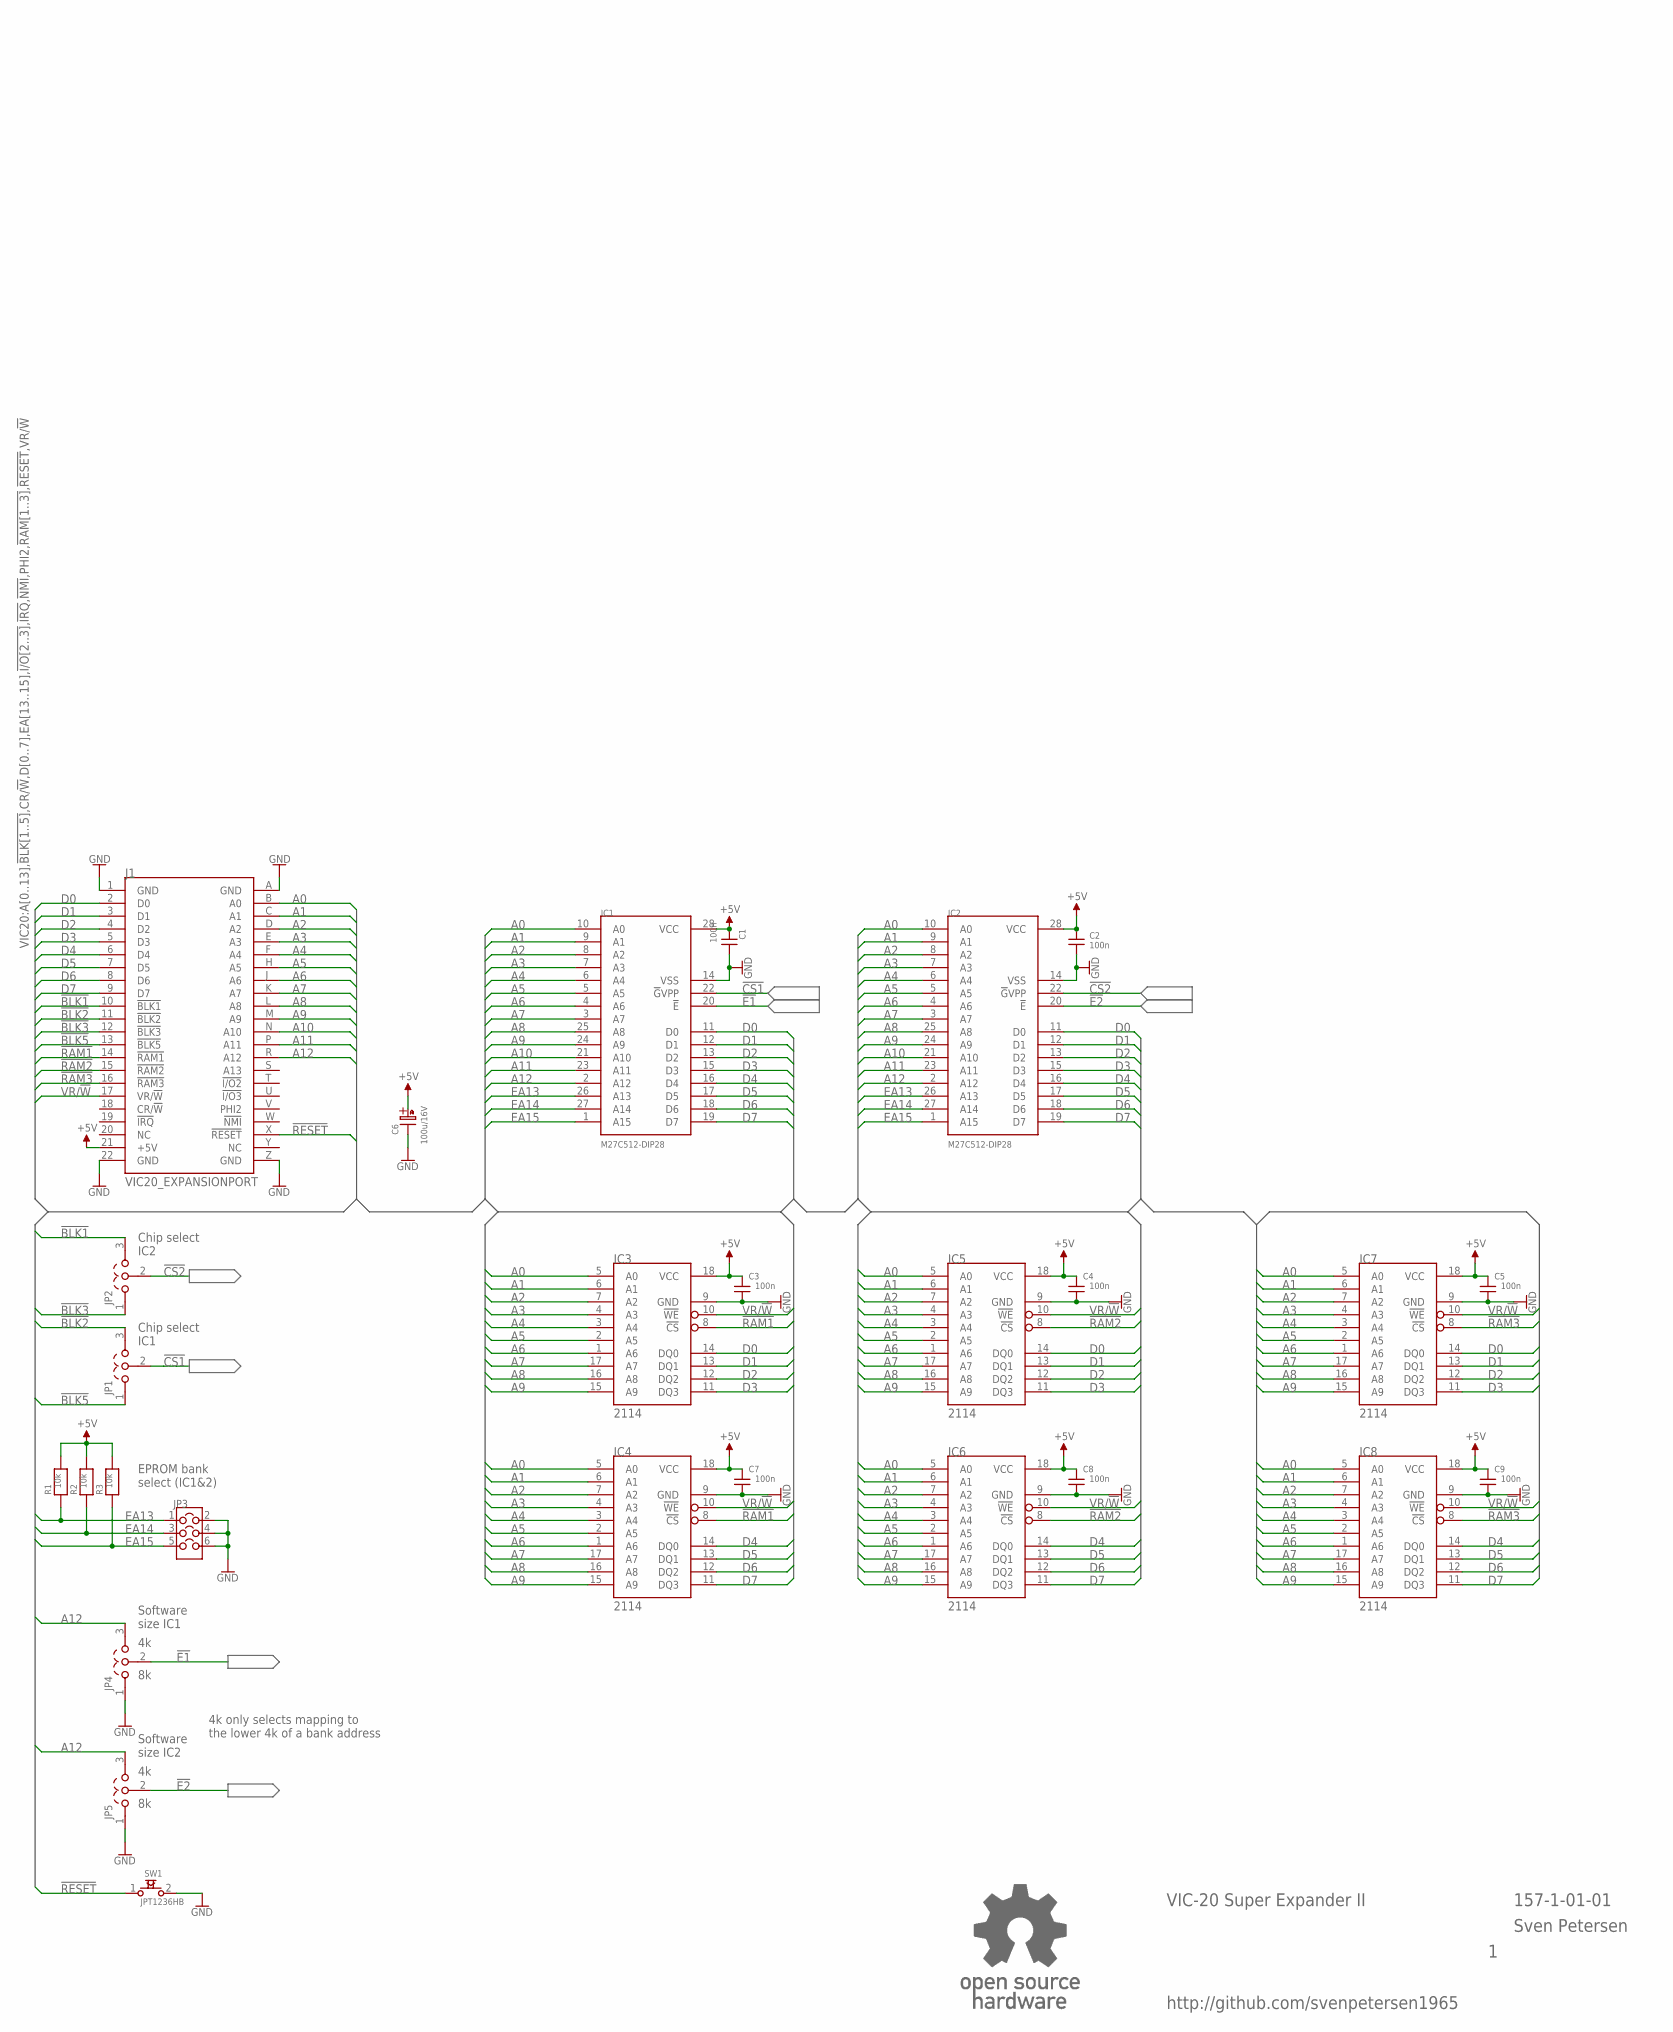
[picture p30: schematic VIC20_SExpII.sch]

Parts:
C1, C2, C3, C4, C5, C7, C8, C9: 100n; C-2,5
C6: 100u/16V; C07/2,5
IC1, IC2: M27C512-DIP28; DIL28-6
IC3, IC4, IC5, IC6, IC7, IC8: 2114; DIL18
J1: VIC20_EXPANSIONPORT; VIC20_EXPANSION
JP1, JP2, JP4, JP5: COMBI-3P
JP3: COMBI-3X2P; COMBI-3X2
R1, R2, R3: 10k; R-10
SW1: JPT1236HB; JTP_1236HB
U$2: OPEN_SOURCE_HW; OPENHW

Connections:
!BLK1: J1.10 (!BLK1), JP2.3
!BLK2: J1.11 (!BLK2), JP1.3
!BLK3: J1.12 (!BLK3), JP2.1
!BLK5: J1.13 (!BLK5), JP1.1
!CS1: IC1.22 (!G!VPP), JP1.2
!CS2: IC2.22 (!G!VPP), JP2.2
!E1: IC1.20 (!E), JP4.2
!E2: IC2.20 (!E), JP5.2
!RAM1: IC3.8 (!CS), IC4.8 (!CS), J1.14 (!RAM1)
!RAM2: IC5.8 (!CS), IC6.8 (!CS), J1.15 (!RAM2)
!RAM3: IC7.8 (!CS), IC8.8 (!CS), J1.16 (!RAM3)
!RESET: J1.X (!RESET), SW1.1
+5V: C1.1, C2.1, C3.2, C4.2, C5.2, C6.A (+), C7.2, C8.2, C9.2, IC1.28 (VCC), IC2.28 (VCC), IC3.18 (VCC), IC4.18 (VCC), IC5.18 (VCC), IC6.18 (VCC), IC7.18 (VCC), IC8.18 (VCC), J1.21 (+5V), R1.2, R2.2, R3.2
A0: IC1.10 (A0), IC2.10 (A0), IC3.5 (A0), IC4.5 (A0), IC5.5 (A0), IC6.5 (A0), IC7.5 (A0), IC8.5 (A0), J1.B (A0)
A1: IC1.9 (A1), IC2.9 (A1), IC3.6 (A1), IC4.6 (A1), IC5.6 (A1), IC6.6 (A1), IC7.6 (A1), IC8.6 (A1), J1.C (A1)
A2: IC1.8 (A2), IC2.8 (A2), IC3.7 (A2), IC4.7 (A2), IC5.7 (A2), IC6.7 (A2), IC7.7 (A2), IC8.7 (A2), J1.D (A2)
A3: IC1.7 (A3), IC2.7 (A3), IC3.4 (A3), IC4.4 (A3), IC5.4 (A3), IC6.4 (A3), IC7.4 (A3), IC8.4 (A3), J1.E (A3)
A4: IC1.6 (A4), IC2.6 (A4), IC3.3 (A4), IC4.3 (A4), IC5.3 (A4), IC6.3 (A4), IC7.3 (A4), IC8.3 (A4), J1.F (A4)
A5: IC1.5 (A5), IC2.5 (A5), IC3.2 (A5), IC4.2 (A5), IC5.2 (A5), IC6.2 (A5), IC7.2 (A5), IC8.2 (A5), J1.H (A5)
A6: IC1.4 (A6), IC2.4 (A6), IC3.1 (A6), IC4.1 (A6), IC5.1 (A6), IC6.1 (A6), IC7.1 (A6), IC8.1 (A6), J1.J (A6)
A7: IC1.3 (A7), IC2.3 (A7), IC3.17 (A7), IC4.17 (A7), IC5.17 (A7), IC6.17 (A7), IC7.17 (A7), IC8.17 (A7), J1.K (A7)
A8: IC1.25 (A8), IC2.25 (A8), IC3.16 (A8), IC4.16 (A8), IC5.16 (A8), IC6.16 (A8), IC7.16 (A8), IC8.16 (A8), J1.L (A8)
A9: IC1.24 (A9), IC2.24 (A9), IC3.15 (A9), IC4.15 (A9), IC5.15 (A9), IC6.15 (A9), IC7.15 (A9), IC8.15 (A9), J1.M (A9)
A10: IC1.21 (A10), IC2.21 (A10), J1.N (A10)
A11: IC1.23 (A11), IC2.23 (A11), J1.P (A11)
A12: IC1.2 (A12), IC2.2 (A12), J1.R (A12), JP4.3, JP5.3
D0: IC1.11 (D0), IC2.11 (D0), IC3.14 (DQ0), IC5.14 (DQ0), IC7.14 (DQ0), J1.2 (D0)
D1: IC1.12 (D1), IC2.12 (D1), IC3.13 (DQ1), IC5.13 (DQ1), IC7.13 (DQ1), J1.3 (D1)
D2: IC1.13 (D2), IC2.13 (D2), IC3.12 (DQ2), IC5.12 (DQ2), IC7.12 (DQ2), J1.4 (D2)
D3: IC1.15 (D3), IC2.15 (D3), IC3.11 (DQ3), IC5.11 (DQ3), IC7.11 (DQ3), J1.5 (D3)
D4: IC1.16 (D4), IC2.16 (D4), IC4.14 (DQ0), IC6.14 (DQ0), IC8.14 (DQ0), J1.6 (D4)
D5: IC1.17 (D5), IC2.17 (D5), IC4.13 (DQ1), IC6.13 (DQ1), IC8.13 (DQ1), J1.7 (D5)
D6: IC1.18 (D6), IC2.18 (D6), IC4.12 (DQ2), IC6.12 (DQ2), IC8.12 (DQ2), J1.8 (D6)
D7: IC1.19 (D7), IC2.19 (D7), IC4.11 (DQ3), IC6.11 (DQ3), IC8.11 (DQ3), J1.9 (D7)
EA13: IC1.26 (A13), IC2.26 (A13), JP3.1, R1.1
EA14: IC1.27 (A14), IC2.27 (A14), JP3.3, R2.1
EA15: IC1.1 (A15), IC2.1 (A15), JP3.5, R3.1
GND: C1.2, C2.2, C3.1, C4.1, C5.1, C6.K (-), C7.1, C8.1, C9.1, IC1.14 (VSS), IC2.14 (VSS), IC3.9 (GND), IC4.9 (GND), IC5.9 (GND), IC6.9 (GND), IC7.9 (GND), IC8.9 (GND), J1.1 (GND), J1.22 (GND), J1.A (GND), J1.Z (GND), JP3.2, JP3.4, JP3.6, JP4.1, JP5.1, SW1.2
NC: J1.20 (NC)
VR/!W: IC3.10 (!WE), IC4.10 (!WE), IC5.10 (!WE), IC6.10 (!WE), IC7.10 (!WE), IC8.10 (!WE), J1.17 (VR/!W)

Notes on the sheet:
VIC-20 Super Expander II
157-1-01-01
Sven Petersen
http://github.com/svenpetersen1965
Software size IC1
Software size IC2
EPROM bank select (IC1&2)
Chip select IC1
Chip select IC2
4k only selects mapping to the lower 4k of a bank address

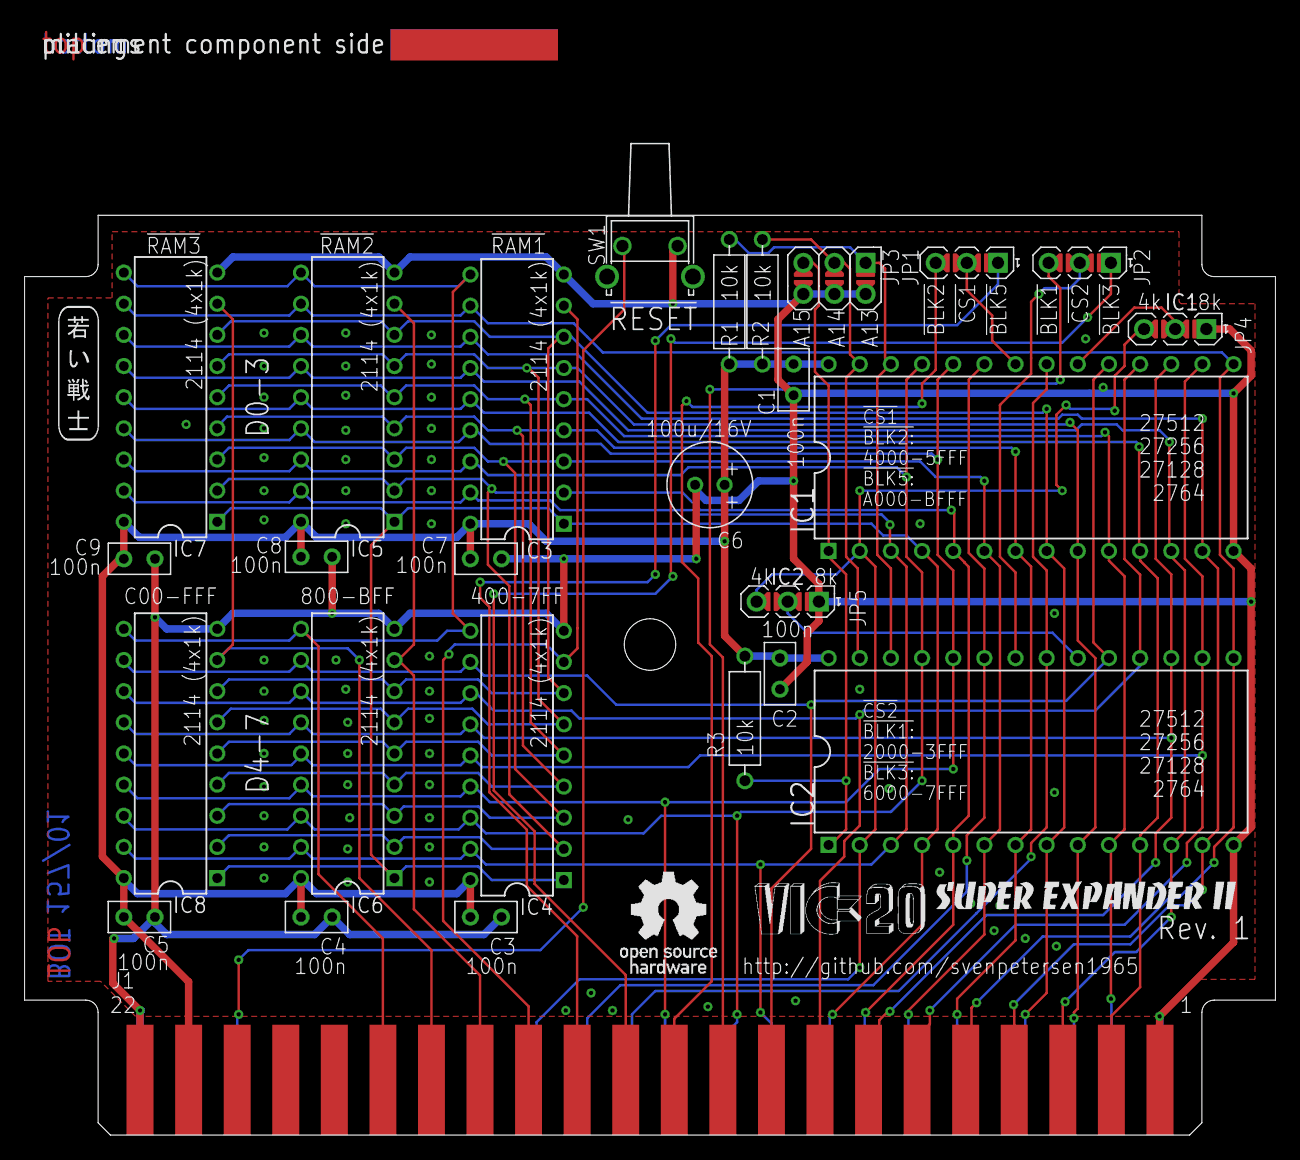
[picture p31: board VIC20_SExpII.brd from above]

Board: 2 copper layers, 102.0 x 75.0 mm, 33 parts (0 on the bottom side), 39 nets.

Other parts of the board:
U$15: SVEN_TAG
U$16: 2LAYER
U$40: PCB-TITLE/
U$42: SUPER_EXPANDER
U$43: VIC-20

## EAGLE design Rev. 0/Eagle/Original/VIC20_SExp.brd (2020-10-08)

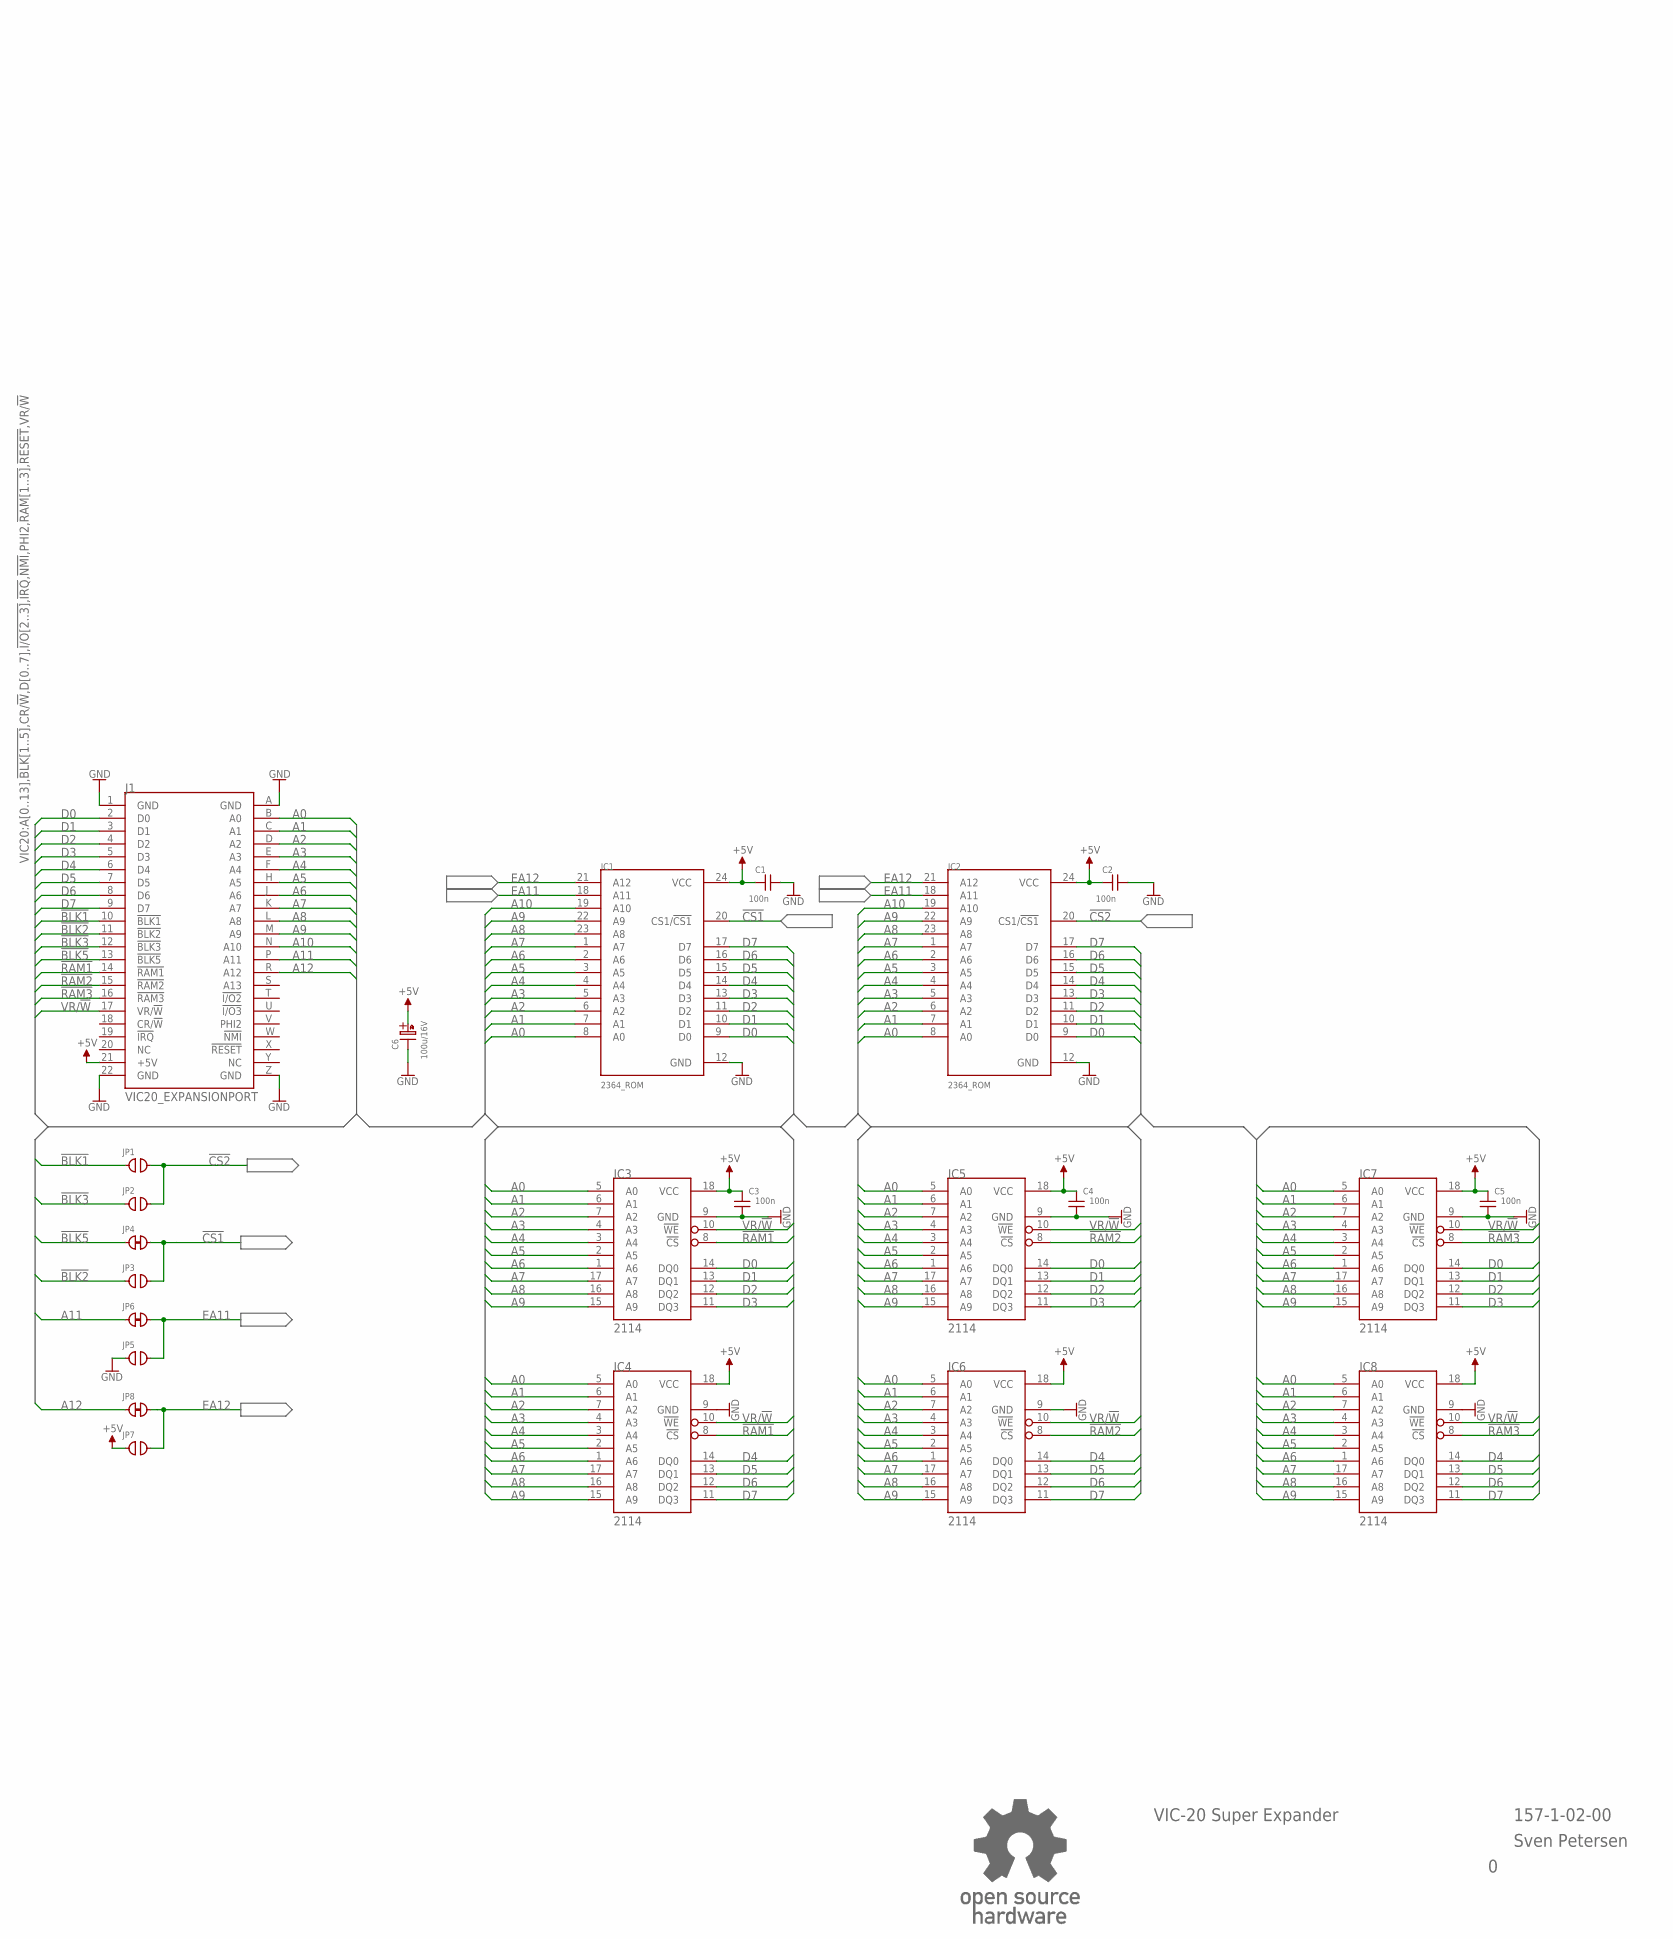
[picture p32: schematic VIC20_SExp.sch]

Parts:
C1, C2, C3, C4, C5: 100n; C-2,5
C6: 100u/16V; C07/2,5
IC1, IC2: 2364_ROM; DIL24-6
IC3, IC4, IC5, IC6, IC7, IC8: 2114; DIL18
J1: VIC20_EXPANSIONPORT; VIC20_EXPANSION
JP1, JP2, JP3, JP5, JP7: OPEN; CP_OP
JP4, JP6, JP8: CLOSED; CP_CL
U$2: OPEN_SOURCE_HW; OPENHW

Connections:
!BLK1: J1.10 (!BLK1), JP1.1
!BLK2: J1.11 (!BLK2), JP3.1
!BLK3: J1.12 (!BLK3), JP2.1
!BLK5: J1.13 (!BLK5), JP4.1
!CS1: IC1.20 (CS1/!CS1), JP3.2, JP4.2
!CS2: IC2.20 (CS1/!CS1), JP1.2, JP2.2
!RAM1: IC3.8 (!CS), IC4.8 (!CS), J1.14 (!RAM1)
!RAM2: IC5.8 (!CS), IC6.8 (!CS), J1.15 (!RAM2)
!RAM3: IC7.8 (!CS), IC8.8 (!CS), J1.16 (!RAM3)
+5V: C1.1, C2.1, C3.2, C4.2, C5.2, C6.A (+), IC1.24 (VCC), IC2.24 (VCC), IC3.18 (VCC), IC4.18 (VCC), IC5.18 (VCC), IC6.18 (VCC), IC7.18 (VCC), IC8.18 (VCC), J1.21 (+5V), JP7.1
A0: IC1.8 (A0), IC2.8 (A0), IC3.5 (A0), IC4.5 (A0), IC5.5 (A0), IC6.5 (A0), IC7.5 (A0), IC8.5 (A0), J1.B (A0)
A1: IC1.7 (A1), IC2.7 (A1), IC3.6 (A1), IC4.6 (A1), IC5.6 (A1), IC6.6 (A1), IC7.6 (A1), IC8.6 (A1), J1.C (A1)
A2: IC1.6 (A2), IC2.6 (A2), IC3.7 (A2), IC4.7 (A2), IC5.7 (A2), IC6.7 (A2), IC7.7 (A2), IC8.7 (A2), J1.D (A2)
A3: IC1.5 (A3), IC2.5 (A3), IC3.4 (A3), IC4.4 (A3), IC5.4 (A3), IC6.4 (A3), IC7.4 (A3), IC8.4 (A3), J1.E (A3)
A4: IC1.4 (A4), IC2.4 (A4), IC3.3 (A4), IC4.3 (A4), IC5.3 (A4), IC6.3 (A4), IC7.3 (A4), IC8.3 (A4), J1.F (A4)
A5: IC1.3 (A5), IC2.3 (A5), IC3.2 (A5), IC4.2 (A5), IC5.2 (A5), IC6.2 (A5), IC7.2 (A5), IC8.2 (A5), J1.H (A5)
A6: IC1.2 (A6), IC2.2 (A6), IC3.1 (A6), IC4.1 (A6), IC5.1 (A6), IC6.1 (A6), IC7.1 (A6), IC8.1 (A6), J1.J (A6)
A7: IC1.1 (A7), IC2.1 (A7), IC3.17 (A7), IC4.17 (A7), IC5.17 (A7), IC6.17 (A7), IC7.17 (A7), IC8.17 (A7), J1.K (A7)
A8: IC1.23 (A8), IC2.23 (A8), IC3.16 (A8), IC4.16 (A8), IC5.16 (A8), IC6.16 (A8), IC7.16 (A8), IC8.16 (A8), J1.L (A8)
A9: IC1.22 (A9), IC2.22 (A9), IC3.15 (A9), IC4.15 (A9), IC5.15 (A9), IC6.15 (A9), IC7.15 (A9), IC8.15 (A9), J1.M (A9)
A10: IC1.19 (A10), IC2.19 (A10), J1.N (A10)
A11: J1.P (A11), JP6.1
A12: J1.R (A12), JP8.1
D0: IC1.9 (D0), IC2.9 (D0), IC3.14 (DQ0), IC5.14 (DQ0), IC7.14 (DQ0), J1.2 (D0)
D1: IC1.10 (D1), IC2.10 (D1), IC3.13 (DQ1), IC5.13 (DQ1), IC7.13 (DQ1), J1.3 (D1)
D2: IC1.11 (D2), IC2.11 (D2), IC3.12 (DQ2), IC5.12 (DQ2), IC7.12 (DQ2), J1.4 (D2)
D3: IC1.13 (D3), IC2.13 (D3), IC3.11 (DQ3), IC5.11 (DQ3), IC7.11 (DQ3), J1.5 (D3)
D4: IC1.14 (D4), IC2.14 (D4), IC4.14 (DQ0), IC6.14 (DQ0), IC8.14 (DQ0), J1.6 (D4)
D5: IC1.15 (D5), IC2.15 (D5), IC4.13 (DQ1), IC6.13 (DQ1), IC8.13 (DQ1), J1.7 (D5)
D6: IC1.16 (D6), IC2.16 (D6), IC4.12 (DQ2), IC6.12 (DQ2), IC8.12 (DQ2), J1.8 (D6)
D7: IC1.17 (D7), IC2.17 (D7), IC4.11 (DQ3), IC6.11 (DQ3), IC8.11 (DQ3), J1.9 (D7)
EA11: IC1.18 (A11), IC2.18 (A11), JP5.2, JP6.2
EA12: IC1.21 (A12), IC2.21 (A12), JP7.2, JP8.2
GND: C1.2, C2.2, C3.1, C4.1, C5.1, C6.K (-), IC1.12 (GND), IC2.12 (GND), IC3.9 (GND), IC4.9 (GND), IC5.9 (GND), IC6.9 (GND), IC7.9 (GND), IC8.9 (GND), J1.1 (GND), J1.22 (GND), J1.A (GND), J1.Z (GND), JP5.1
NC: J1.20 (NC)
VR/!W: IC3.10 (!WE), IC4.10 (!WE), IC5.10 (!WE), IC6.10 (!WE), IC7.10 (!WE), IC8.10 (!WE), J1.17 (VR/!W)

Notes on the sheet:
VIC-20 Super Expander
157-1-02-00
Sven Petersen

Board: 2 copper layers, 25 parts (0 on the bottom side), 35 nets, no tracks yet.

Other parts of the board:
U$40: PCB-TITLE/

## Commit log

2020-12-12 Calculation added
    [VIC20_SExpII_BOM_v0_0_calc.xlsx]
2021-07-16 Rev. 1 released
    4k/8k jumper & fancy new logo
    [VIC20_SExpII.brd, VIC20_SExpII.csv, VIC20_SExpII.sch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]
